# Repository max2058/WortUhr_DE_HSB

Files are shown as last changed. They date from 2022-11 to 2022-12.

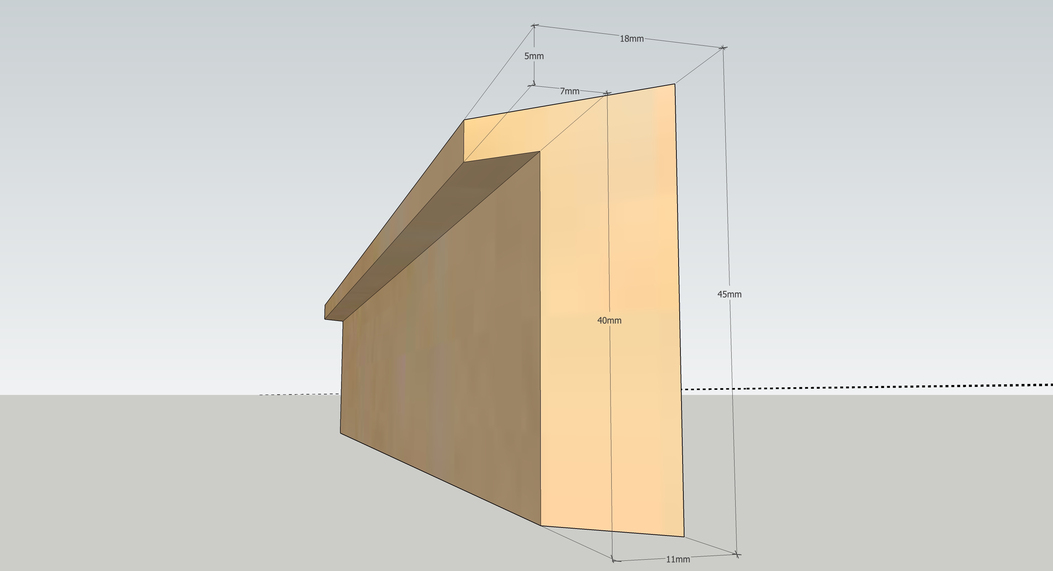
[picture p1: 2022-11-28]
02_Konstruktion_und_Layouts/25x25cm/Rahmen/Rahmen02.jpg

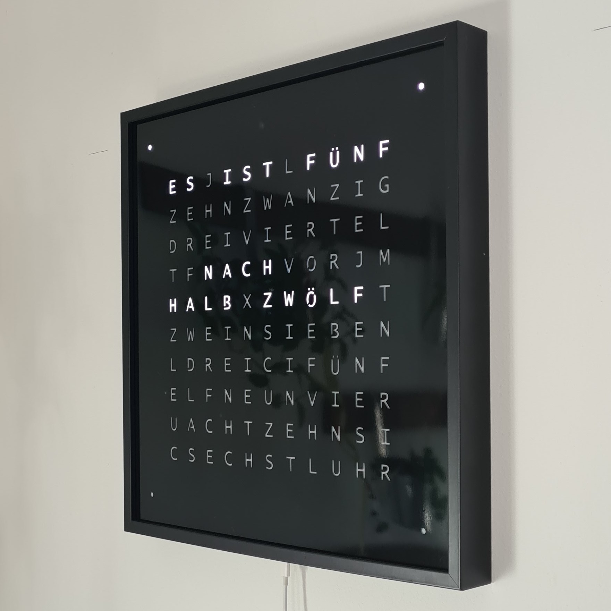
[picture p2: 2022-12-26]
10_Inbetriebnahme/01_Bilder/20220212_113719~2.jpg

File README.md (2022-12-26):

# WortUhr / WordClock

Projekt Wortuhr.... Text

## Hinweis

Hier liegt das "Gesamte" WortUhr Projekt und nicht nur der Quellcode der Software...

## Inhalt

- 02_Konstruktion_und_Layouts.             --> 3D Zeichungen Uhr, Rahmen; 3D-Druck Teile, Schriftart, PDF- Layout 
- 03_Programm_ESP8266/WordUhr_DE_Esp8266.  --> C-Quellcode Programm Arduino ESP8266
- 10_Inbetriebnahme        --> Hinweise Inbetriebnhame (pdf), Diverse Bilder
- 50_SorbischeWordUhrDok.  --> Ist in Planung, Erste Dokumente
- 99_WeitereUnterlagen.    --> Datenblätter ESP8266

... in Bearbeitung
...

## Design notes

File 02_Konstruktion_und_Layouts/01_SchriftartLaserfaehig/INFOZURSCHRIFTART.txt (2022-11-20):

Bei meinen Layouts habe ich die Schriftart '84Lucida-Console' selbst angepasst und "erweitert" um eine Laserbare bzw Plottbare Schriftart zu haben. "Lucida-Console" sieht ganz cool aus, ist im Original aber keine "Standsbare" Schriftart..}

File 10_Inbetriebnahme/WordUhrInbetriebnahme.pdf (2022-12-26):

# WORTUHR / WORDCLOCK

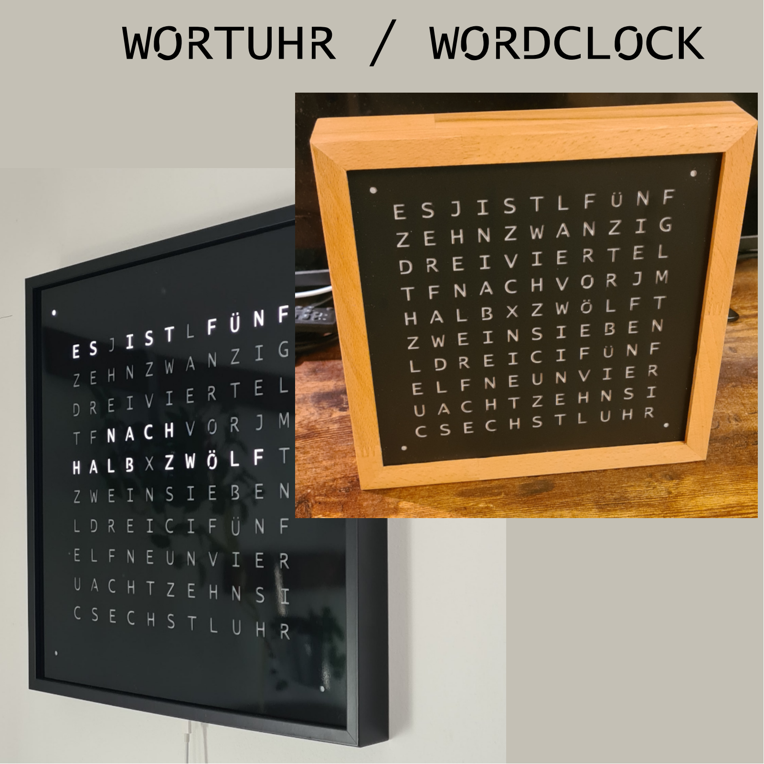
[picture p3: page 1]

# AUFBAU

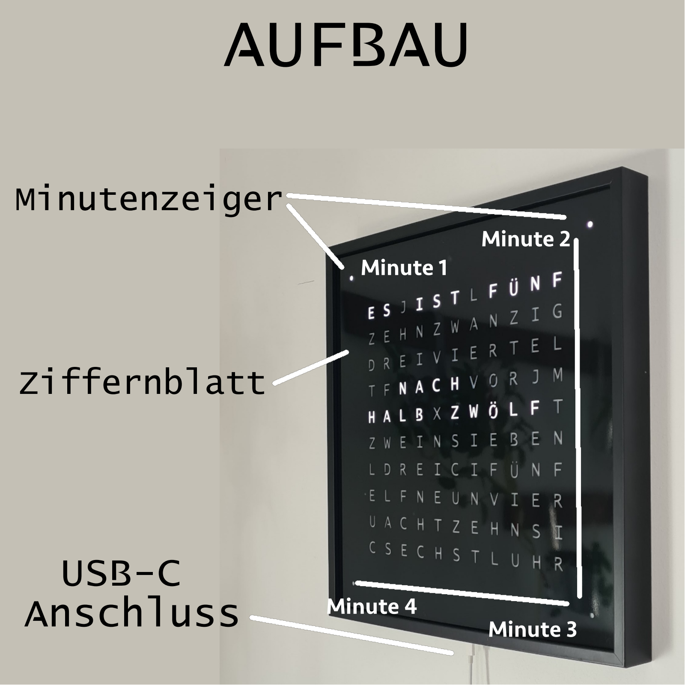
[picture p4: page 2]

# USB-C Anschluss

## Ziffernblatt

## Minutenzeiger

### Minute 1

### Minute 2

### Minute 3

### Minute 4

1. Die WortUhr mit dem beigelegten USB-Kabel + Netzteil an eine Steckdose stecken.
2. Die Uhr startet und führt einen LED Test durch.
3. Nun mit einem Smartphone, Tablet oder PC sich über WLAN mit der WortUhr verbinden.

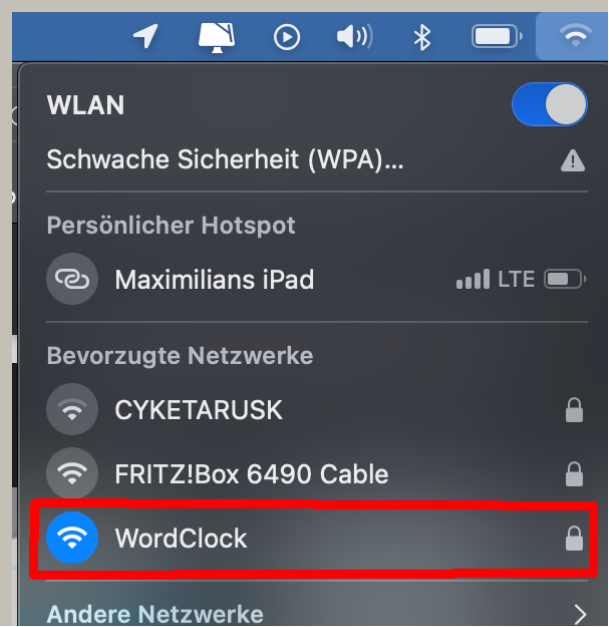
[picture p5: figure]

NAME: "WordClock" oder
"WortUhr"
(je nach Version)

Passwort: "wortuhr123"

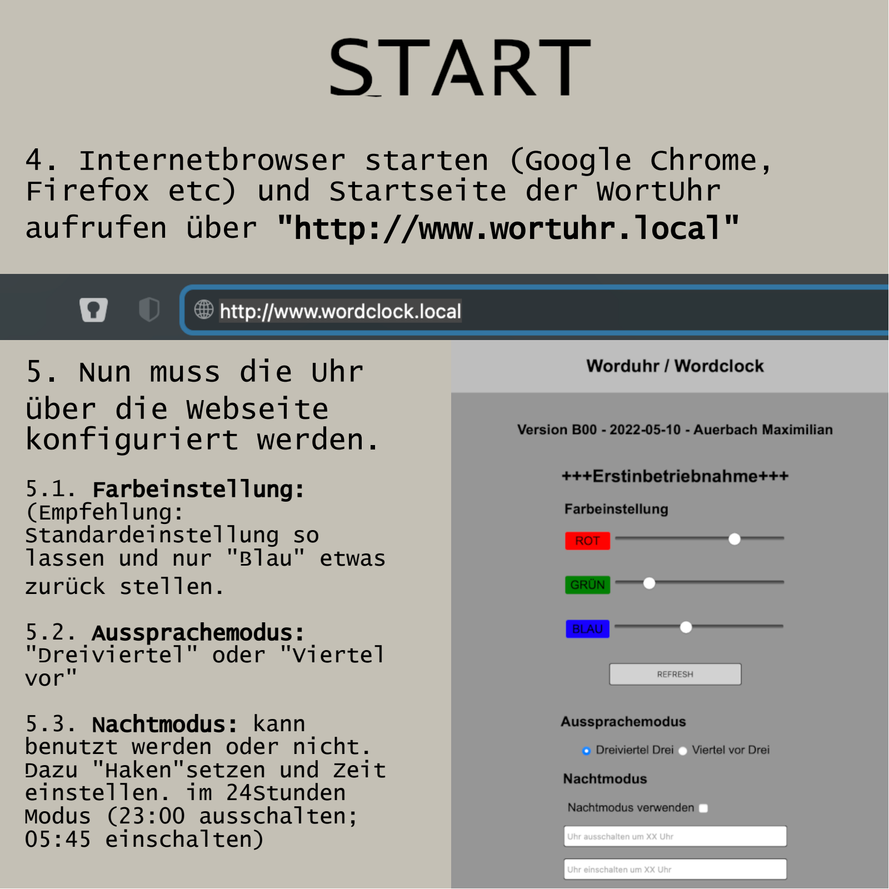
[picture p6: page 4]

4. Internetbrowser starten (Google Chrome, Firefox etc) und Startseite der WortUhr aufrufen über "http://www.wortuhr.local"
5. Nun muss die Uhr
über die Webseite
konfiguriert werden.
5.1. Farbeinstellung:
(Empfehlung:
Standardeinstellung so
lassen und nur "Blau" etwas zurück stellen.
5.2. Aussprachemodus:
"Dreiviertel" oder "Viertel vor"
5.3. Nachtmodus: kann
benutzt werden oder nicht. Dazu "Haken"setzen und Zeit einstellen. im 24Stunden
Modus (23:00 ausschalten;
05:45 einschalten)

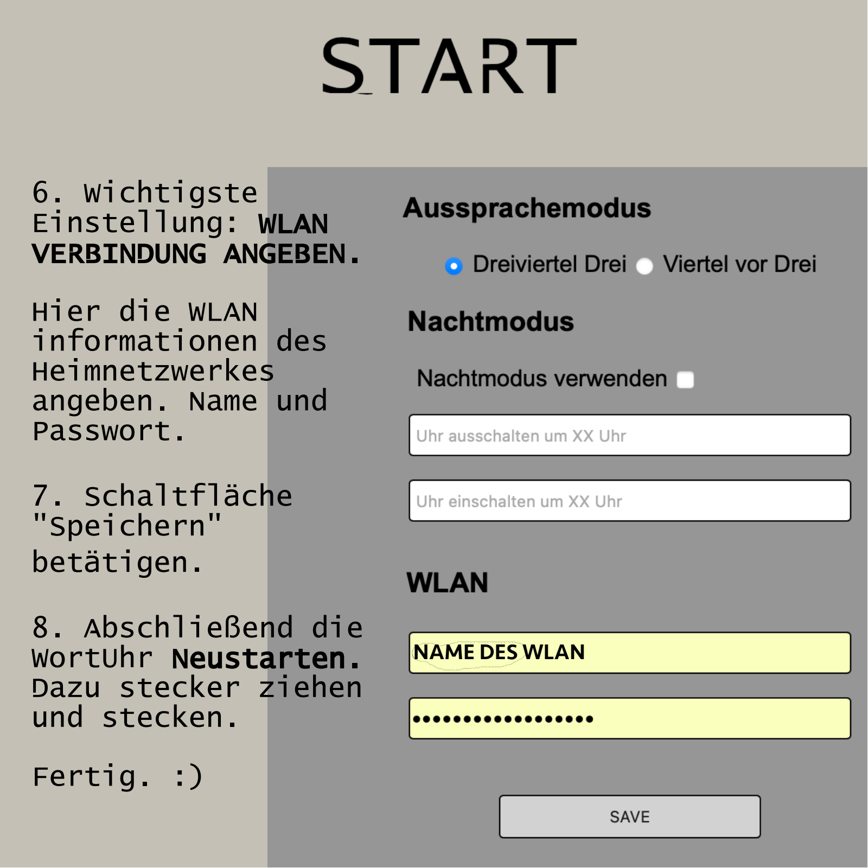
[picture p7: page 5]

6. Wichtigste
Einstellung: WLAN
VERBINDUNG ANGEBEN.

Hier die WLAN
informationen des
Heimnetzwerkes
angeben. Name und
Passwort.
7. Schaltfläche
"Speichern"
betätigen.
8. Abschließend die
WortUhr Neustarten.
Dazu stecker ziehen
und stecken.

Fertig. :)

NAME DES WLAN

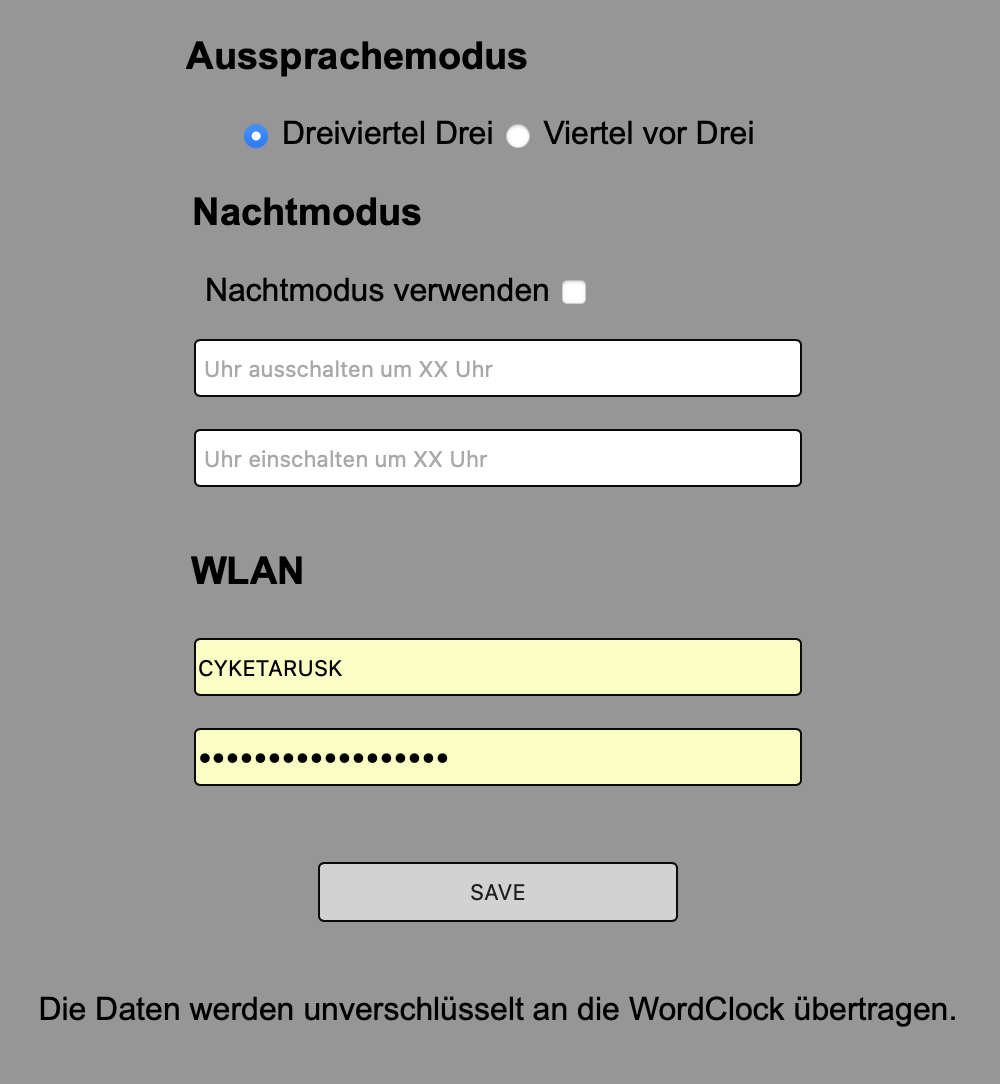
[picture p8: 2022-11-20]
10_Inbetriebnahme/01_Bilder/Bildschirmfoto 2022-04-28 um 17.10.47.png

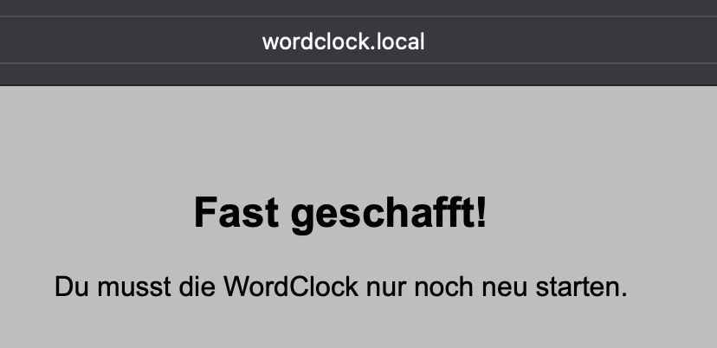
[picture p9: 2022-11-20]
10_Inbetriebnahme/01_Bilder/Bildschirmfoto 2022-04-28 um 17.11.06.png

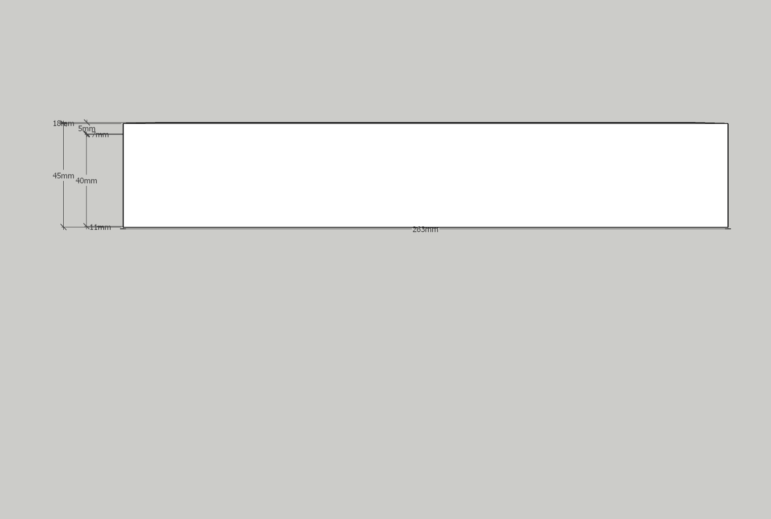
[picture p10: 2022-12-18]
02_Konstruktion_und_Layouts/25x25cm/Rahmen/Rahmen04_Hinten.png

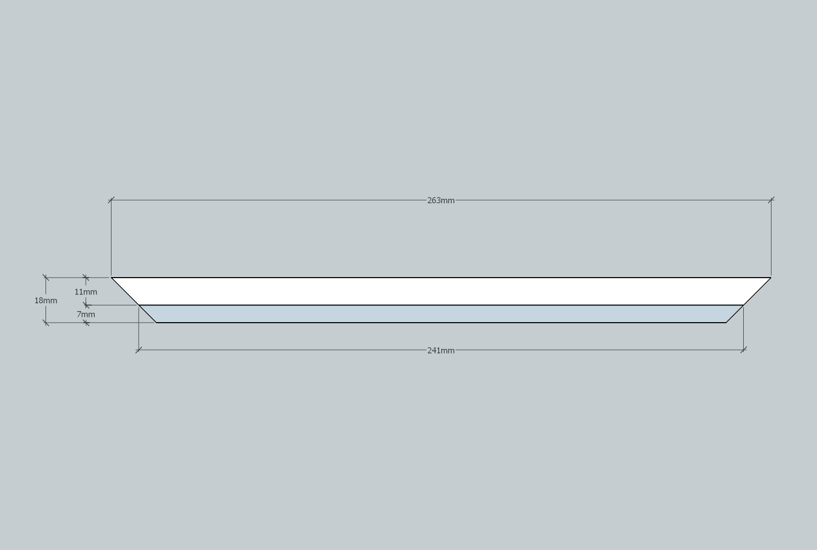
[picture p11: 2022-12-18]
02_Konstruktion_und_Layouts/25x25cm/Rahmen/Rahmen02_Unten.png

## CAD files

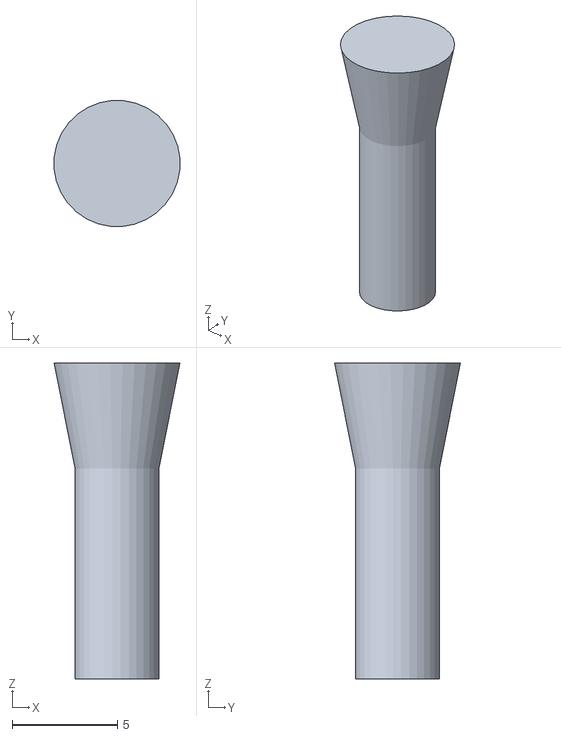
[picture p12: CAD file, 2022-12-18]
02_Konstruktion_und_Layouts/25x25cm/Schliessstem.stl
5.98 x 5.98 x 15.0

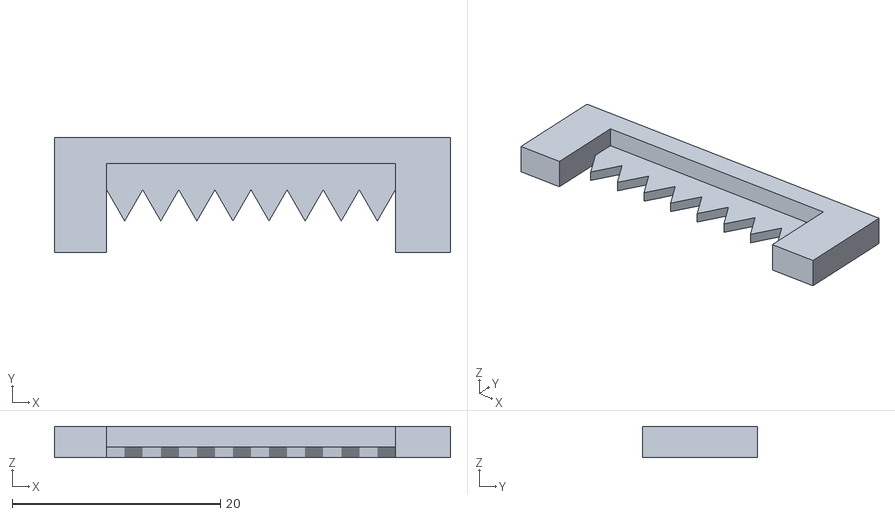
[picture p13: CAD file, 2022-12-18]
02_Konstruktion_und_Layouts/WandhalterNagelBilderrahmen_klein.stl
38.0 x 11.0 x 3.00

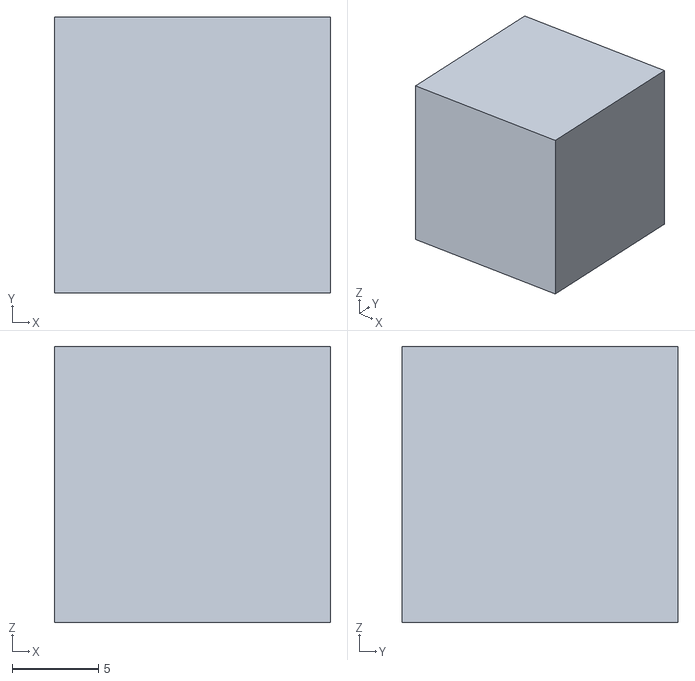
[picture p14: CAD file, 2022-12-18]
02_Konstruktion_und_Layouts/25x25cm/Abstandshalter.stl
16.0 x 16.0 x 16.0

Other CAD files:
02_Konstruktion_und_Layouts/25x25cm/LayoutLED60ProMeter.skp
02_Konstruktion_und_Layouts/25x25cm/LayoutLED60ProMeter~.skp
02_Konstruktion_und_Layouts/WandhalterNagelBilderrahmen_klein.skp
02_Konstruktion_und_Layouts/WandhalterNagelBilderrahmen_klein~.skp

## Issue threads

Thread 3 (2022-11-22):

Manchmal wird der ESP8266 zerstört.

max2058, 2022-11-22:
dann qualmt ein Bauteil ab... Die Vermutung ist, dass die LEDs zu hell eingestellt werden und die Stromaufnahme zu groß ist.. Das passiert bevorzugt gleich immer zu beginn beim LED test während der IBN... weil da sind kurz alle Lampen an....
Problem:
- ist nur eine Vermutung...
- das SMD Bauteil welches durchraucht --> keine Ahnung was das für eine Aufgabe hat.

max2058, 2022-11-25:
Habe die LED Helligkeit während des LED testes nun auf ein Minimum verringert..

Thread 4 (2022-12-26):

Nachtmodus kann unsauber konfiguriert werden.

max2058, 2022-12-26:
wenn man bei der Inbetriebnahme nur den Haken bei "Nachtmodus" setzt, und keine Uhrzeiten einträgt, dann geht die Uhr einfach direkt aus nach dem start... und der Nachrmodus ist dann quasi von 0 bis 24 Uhr

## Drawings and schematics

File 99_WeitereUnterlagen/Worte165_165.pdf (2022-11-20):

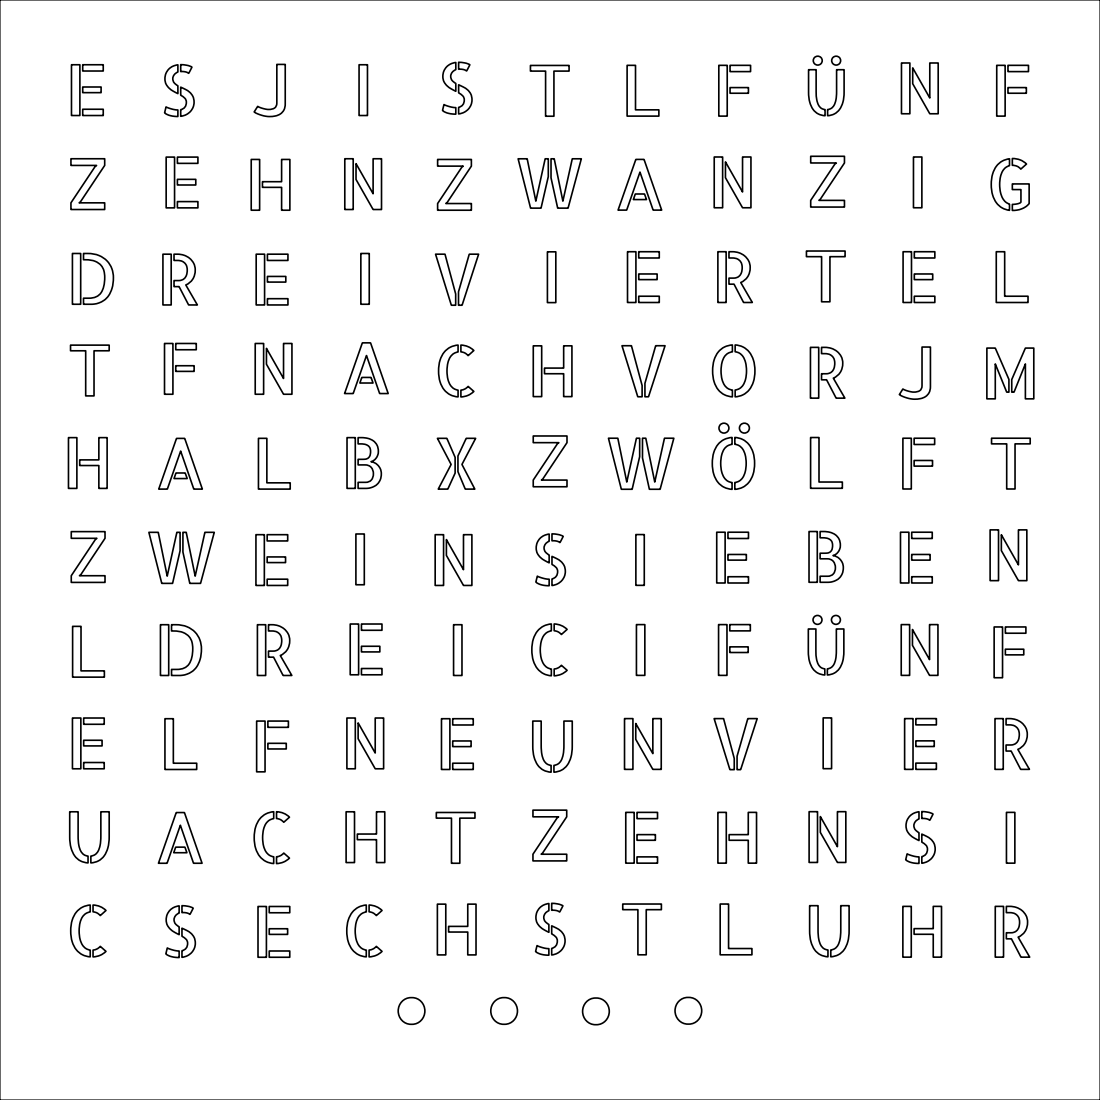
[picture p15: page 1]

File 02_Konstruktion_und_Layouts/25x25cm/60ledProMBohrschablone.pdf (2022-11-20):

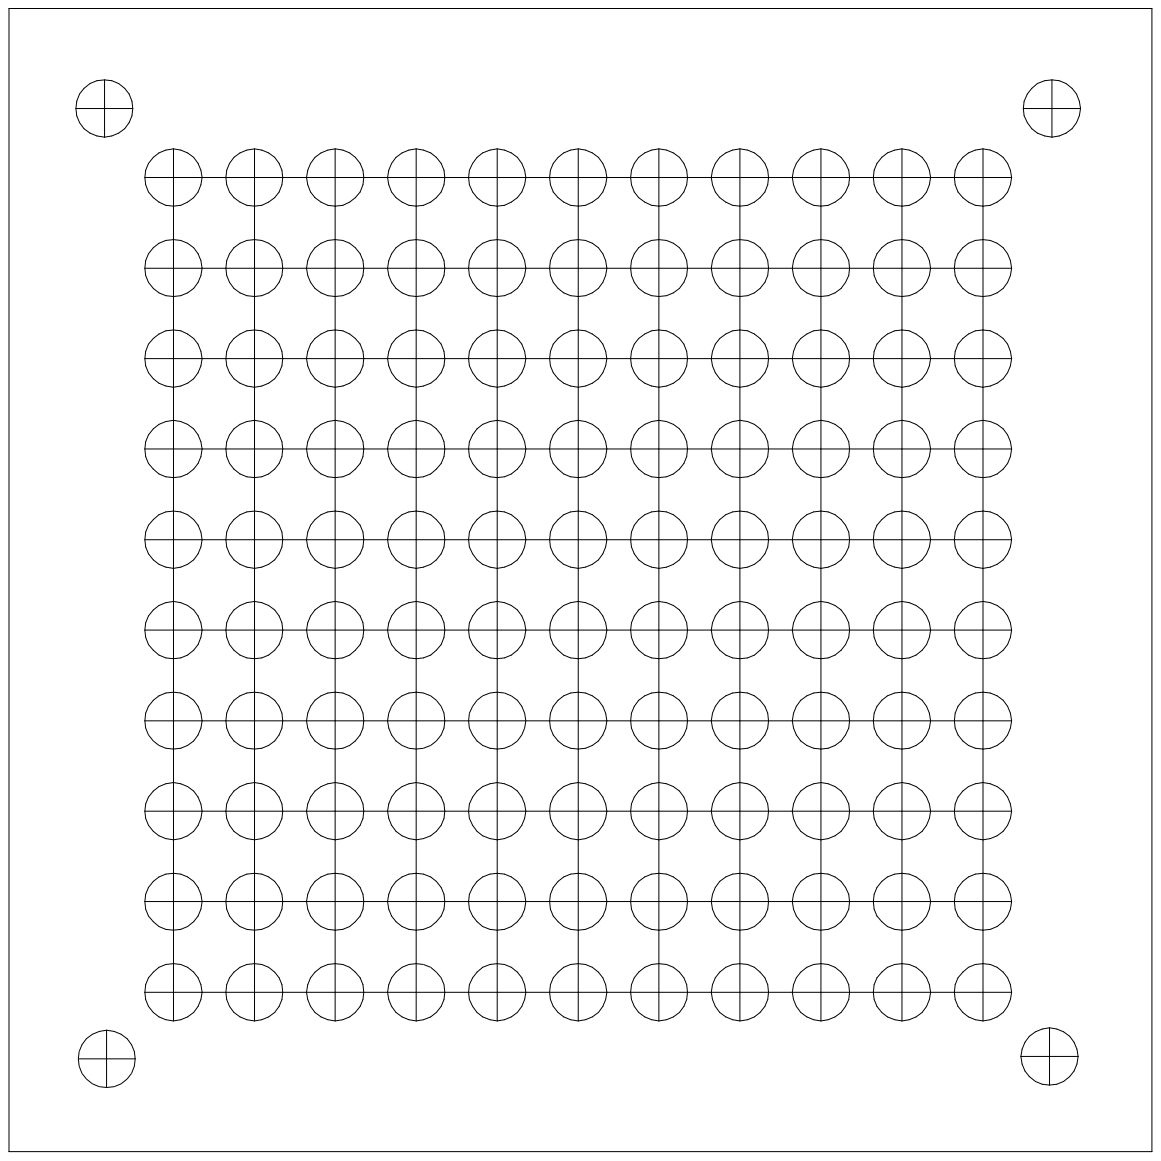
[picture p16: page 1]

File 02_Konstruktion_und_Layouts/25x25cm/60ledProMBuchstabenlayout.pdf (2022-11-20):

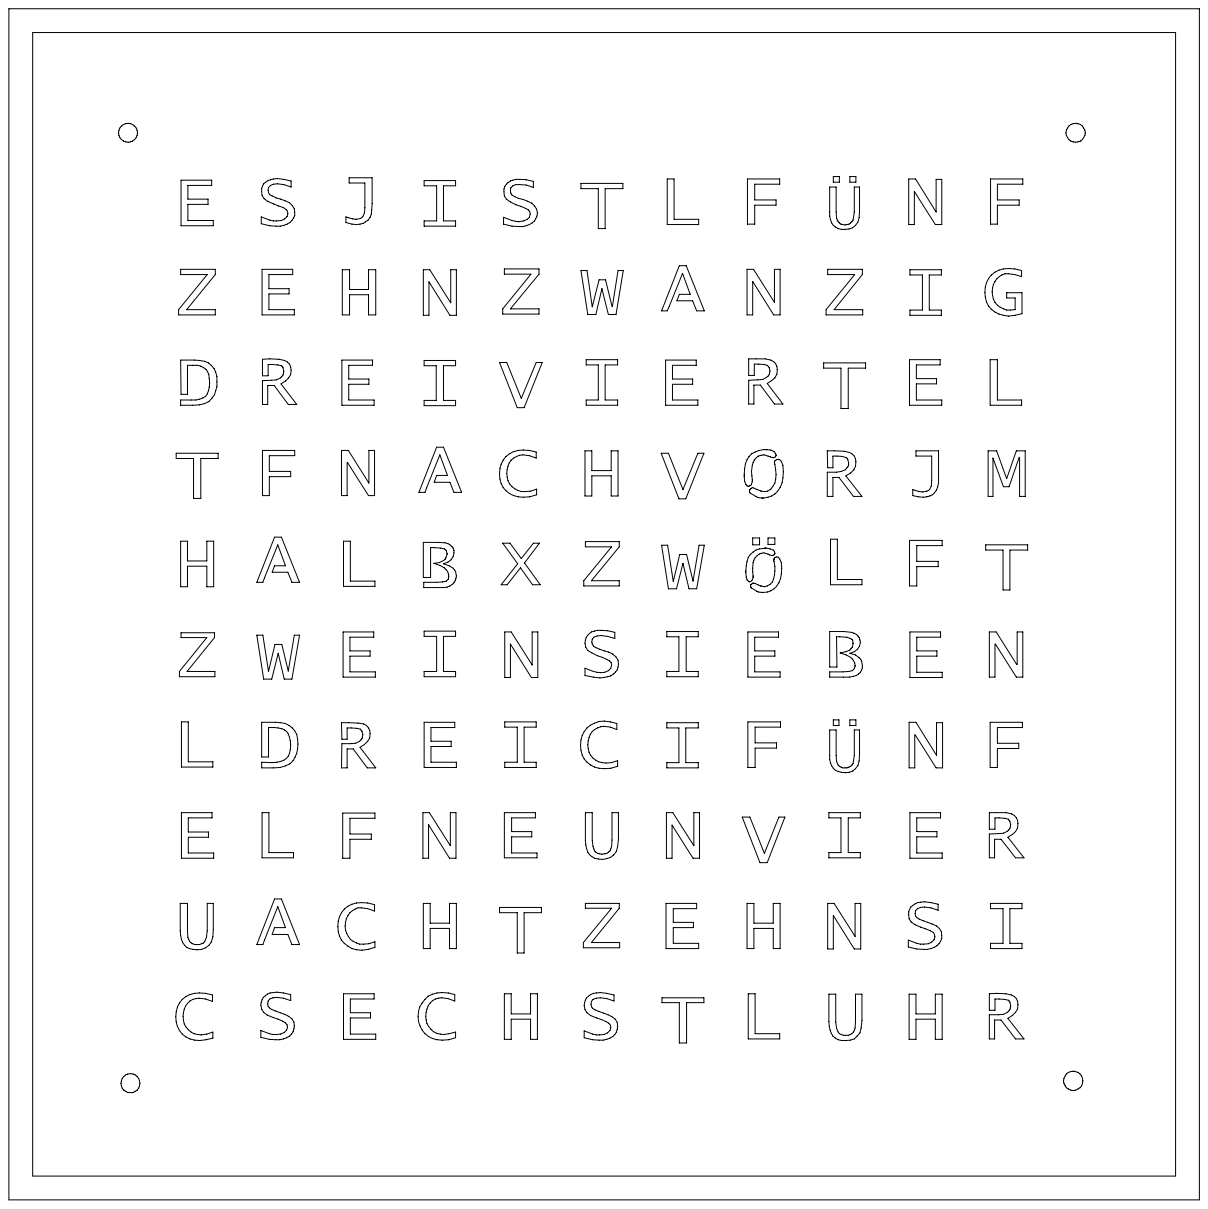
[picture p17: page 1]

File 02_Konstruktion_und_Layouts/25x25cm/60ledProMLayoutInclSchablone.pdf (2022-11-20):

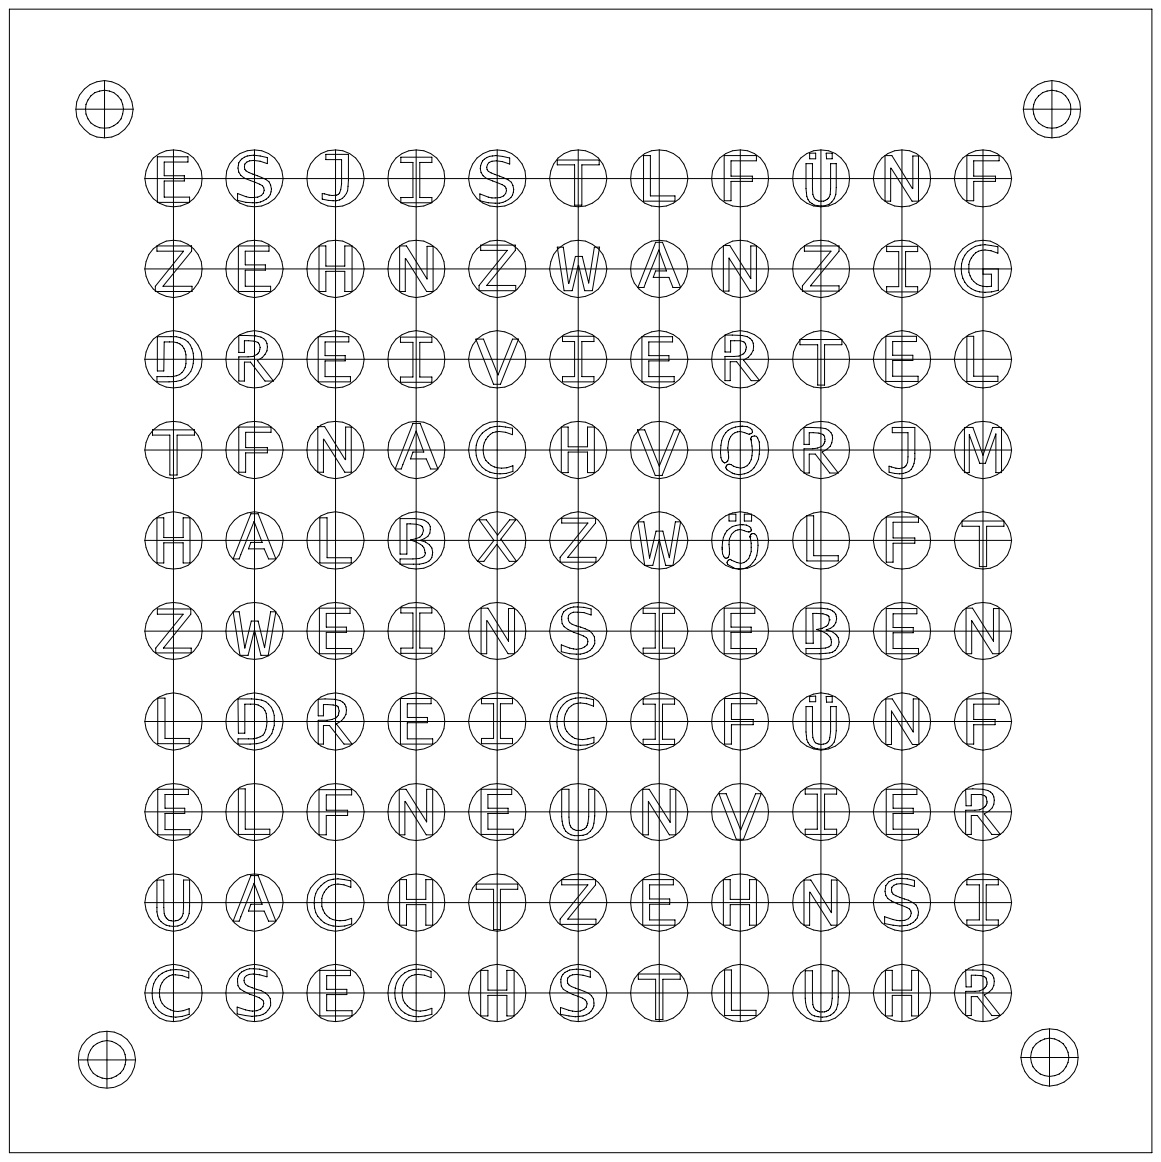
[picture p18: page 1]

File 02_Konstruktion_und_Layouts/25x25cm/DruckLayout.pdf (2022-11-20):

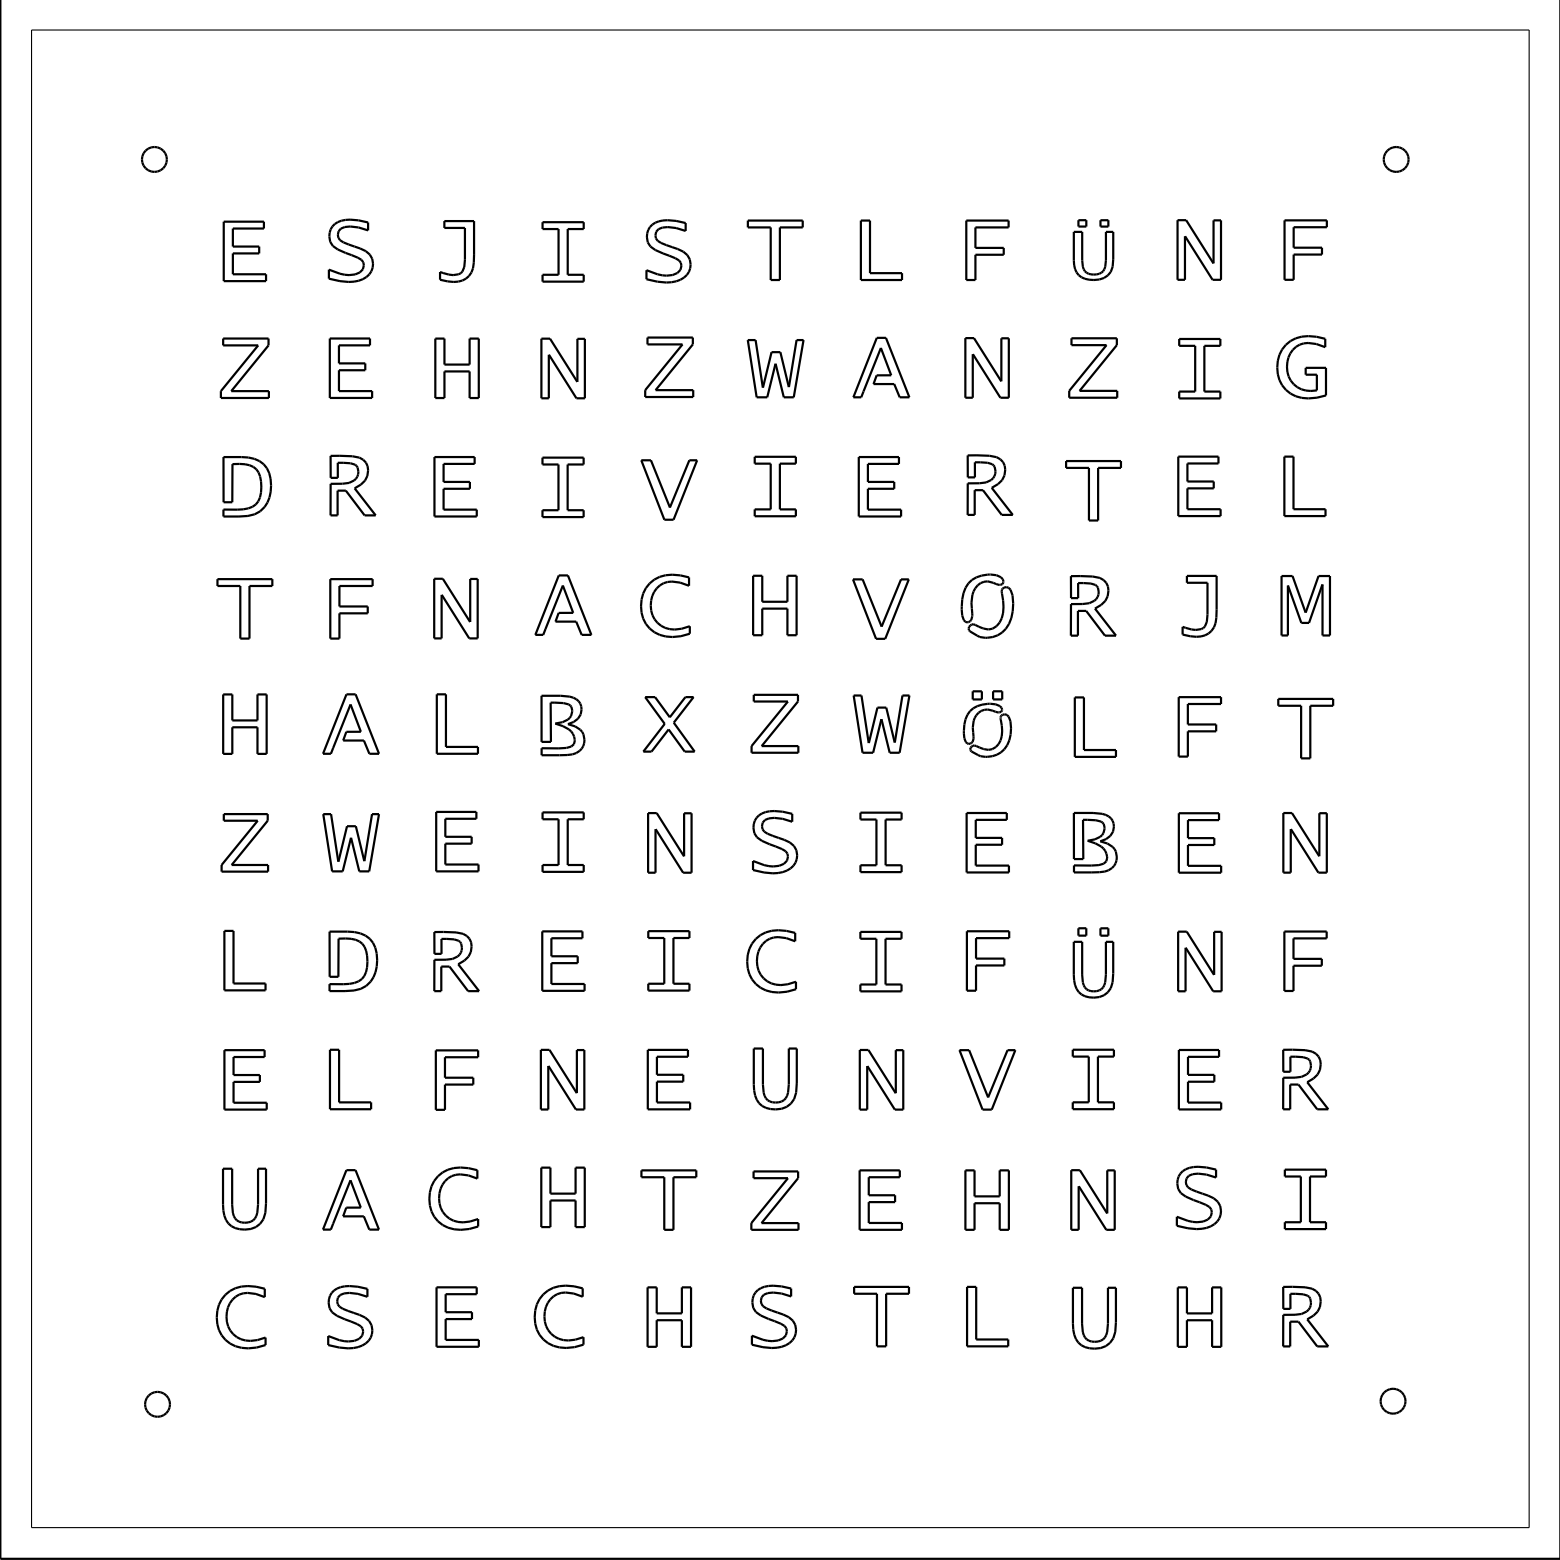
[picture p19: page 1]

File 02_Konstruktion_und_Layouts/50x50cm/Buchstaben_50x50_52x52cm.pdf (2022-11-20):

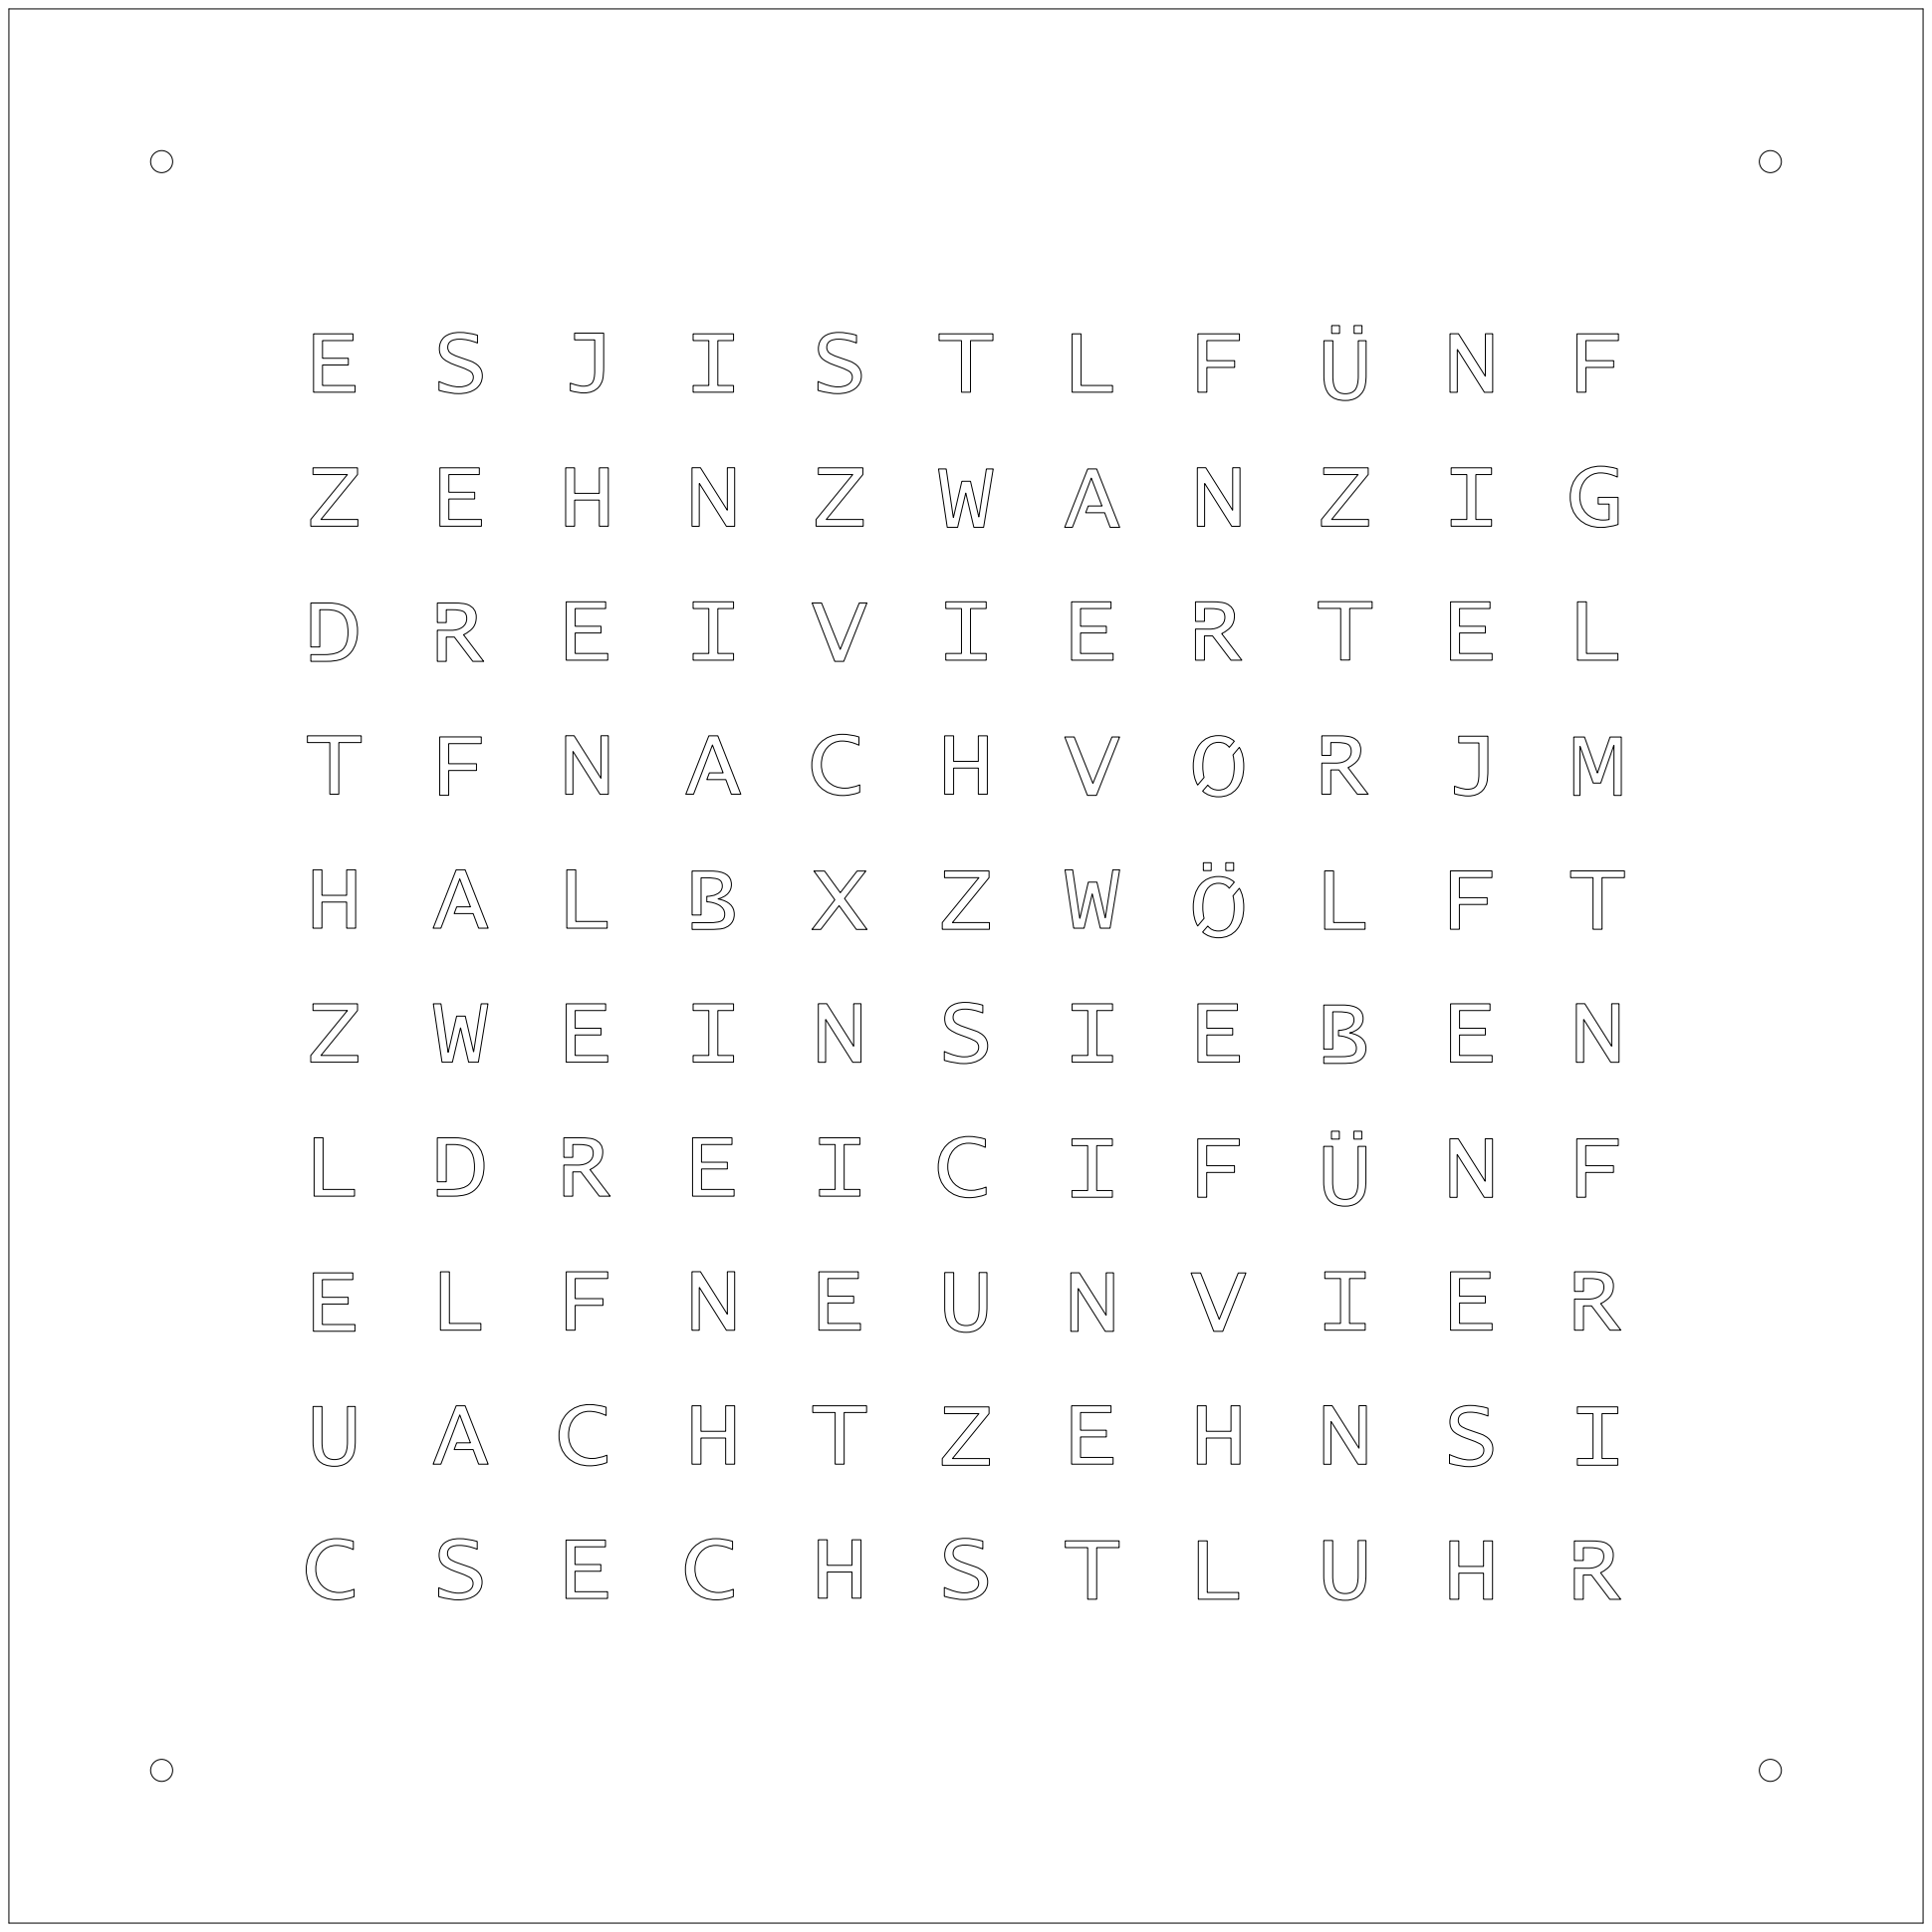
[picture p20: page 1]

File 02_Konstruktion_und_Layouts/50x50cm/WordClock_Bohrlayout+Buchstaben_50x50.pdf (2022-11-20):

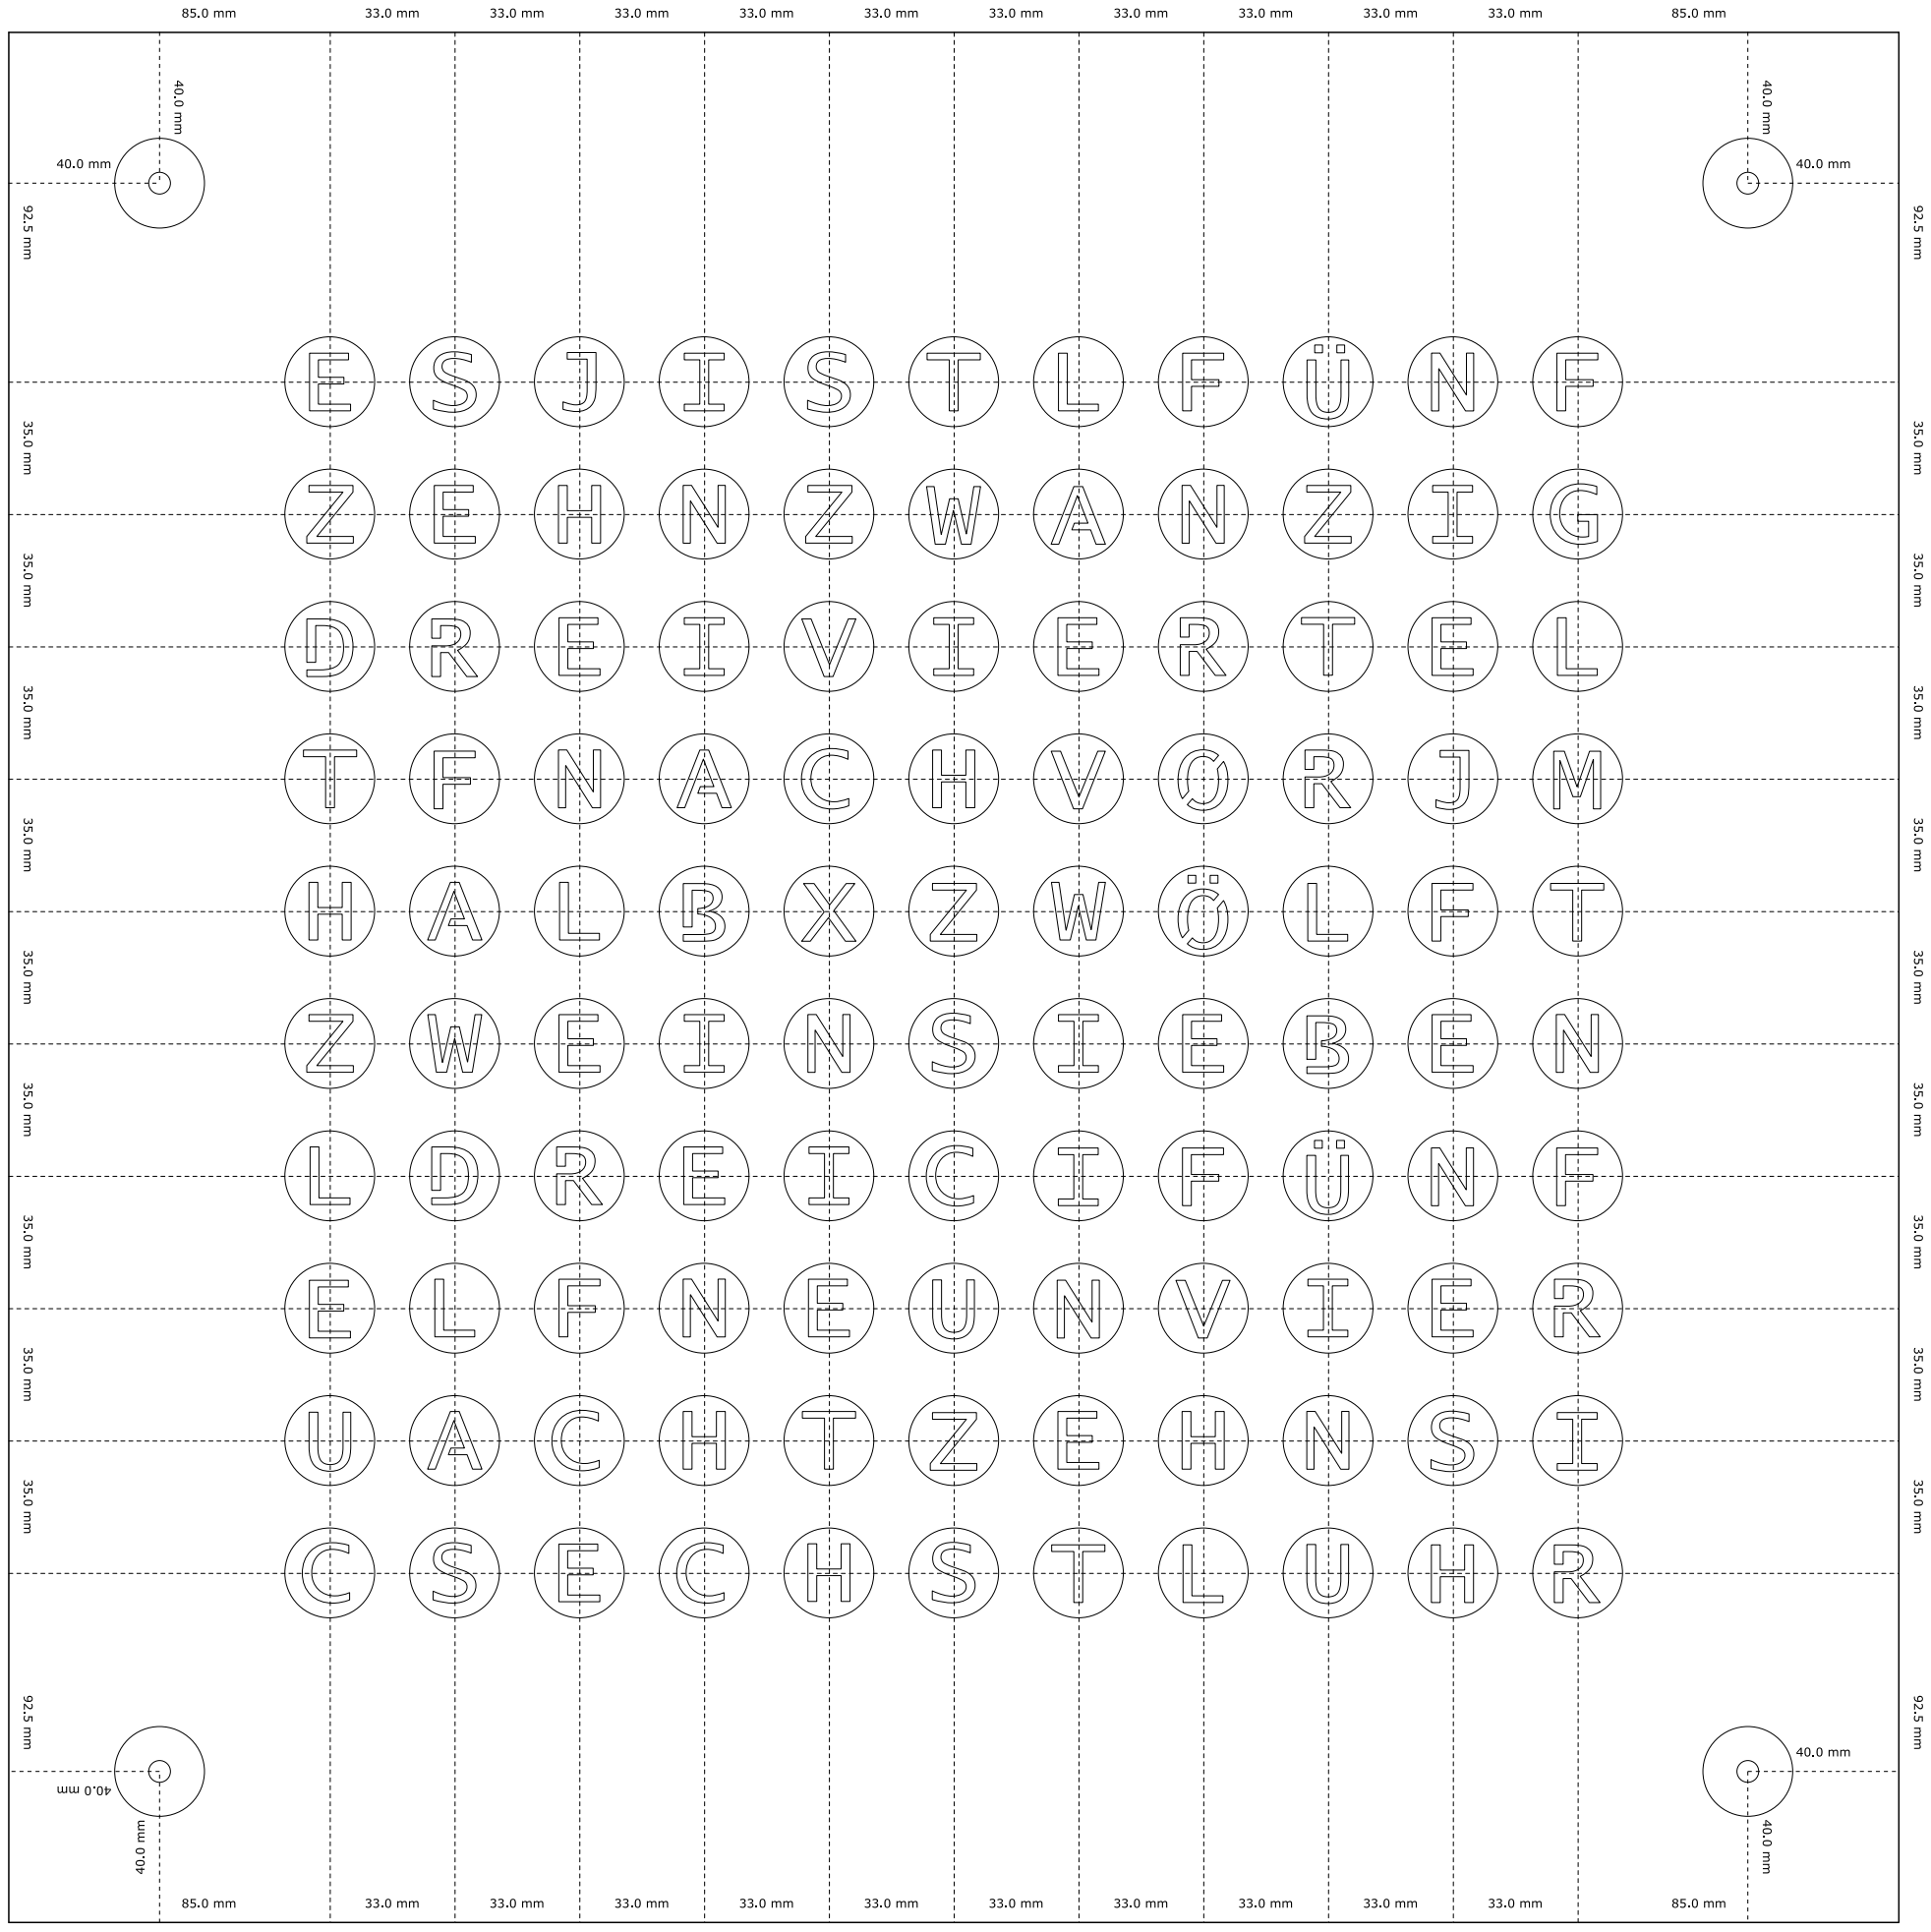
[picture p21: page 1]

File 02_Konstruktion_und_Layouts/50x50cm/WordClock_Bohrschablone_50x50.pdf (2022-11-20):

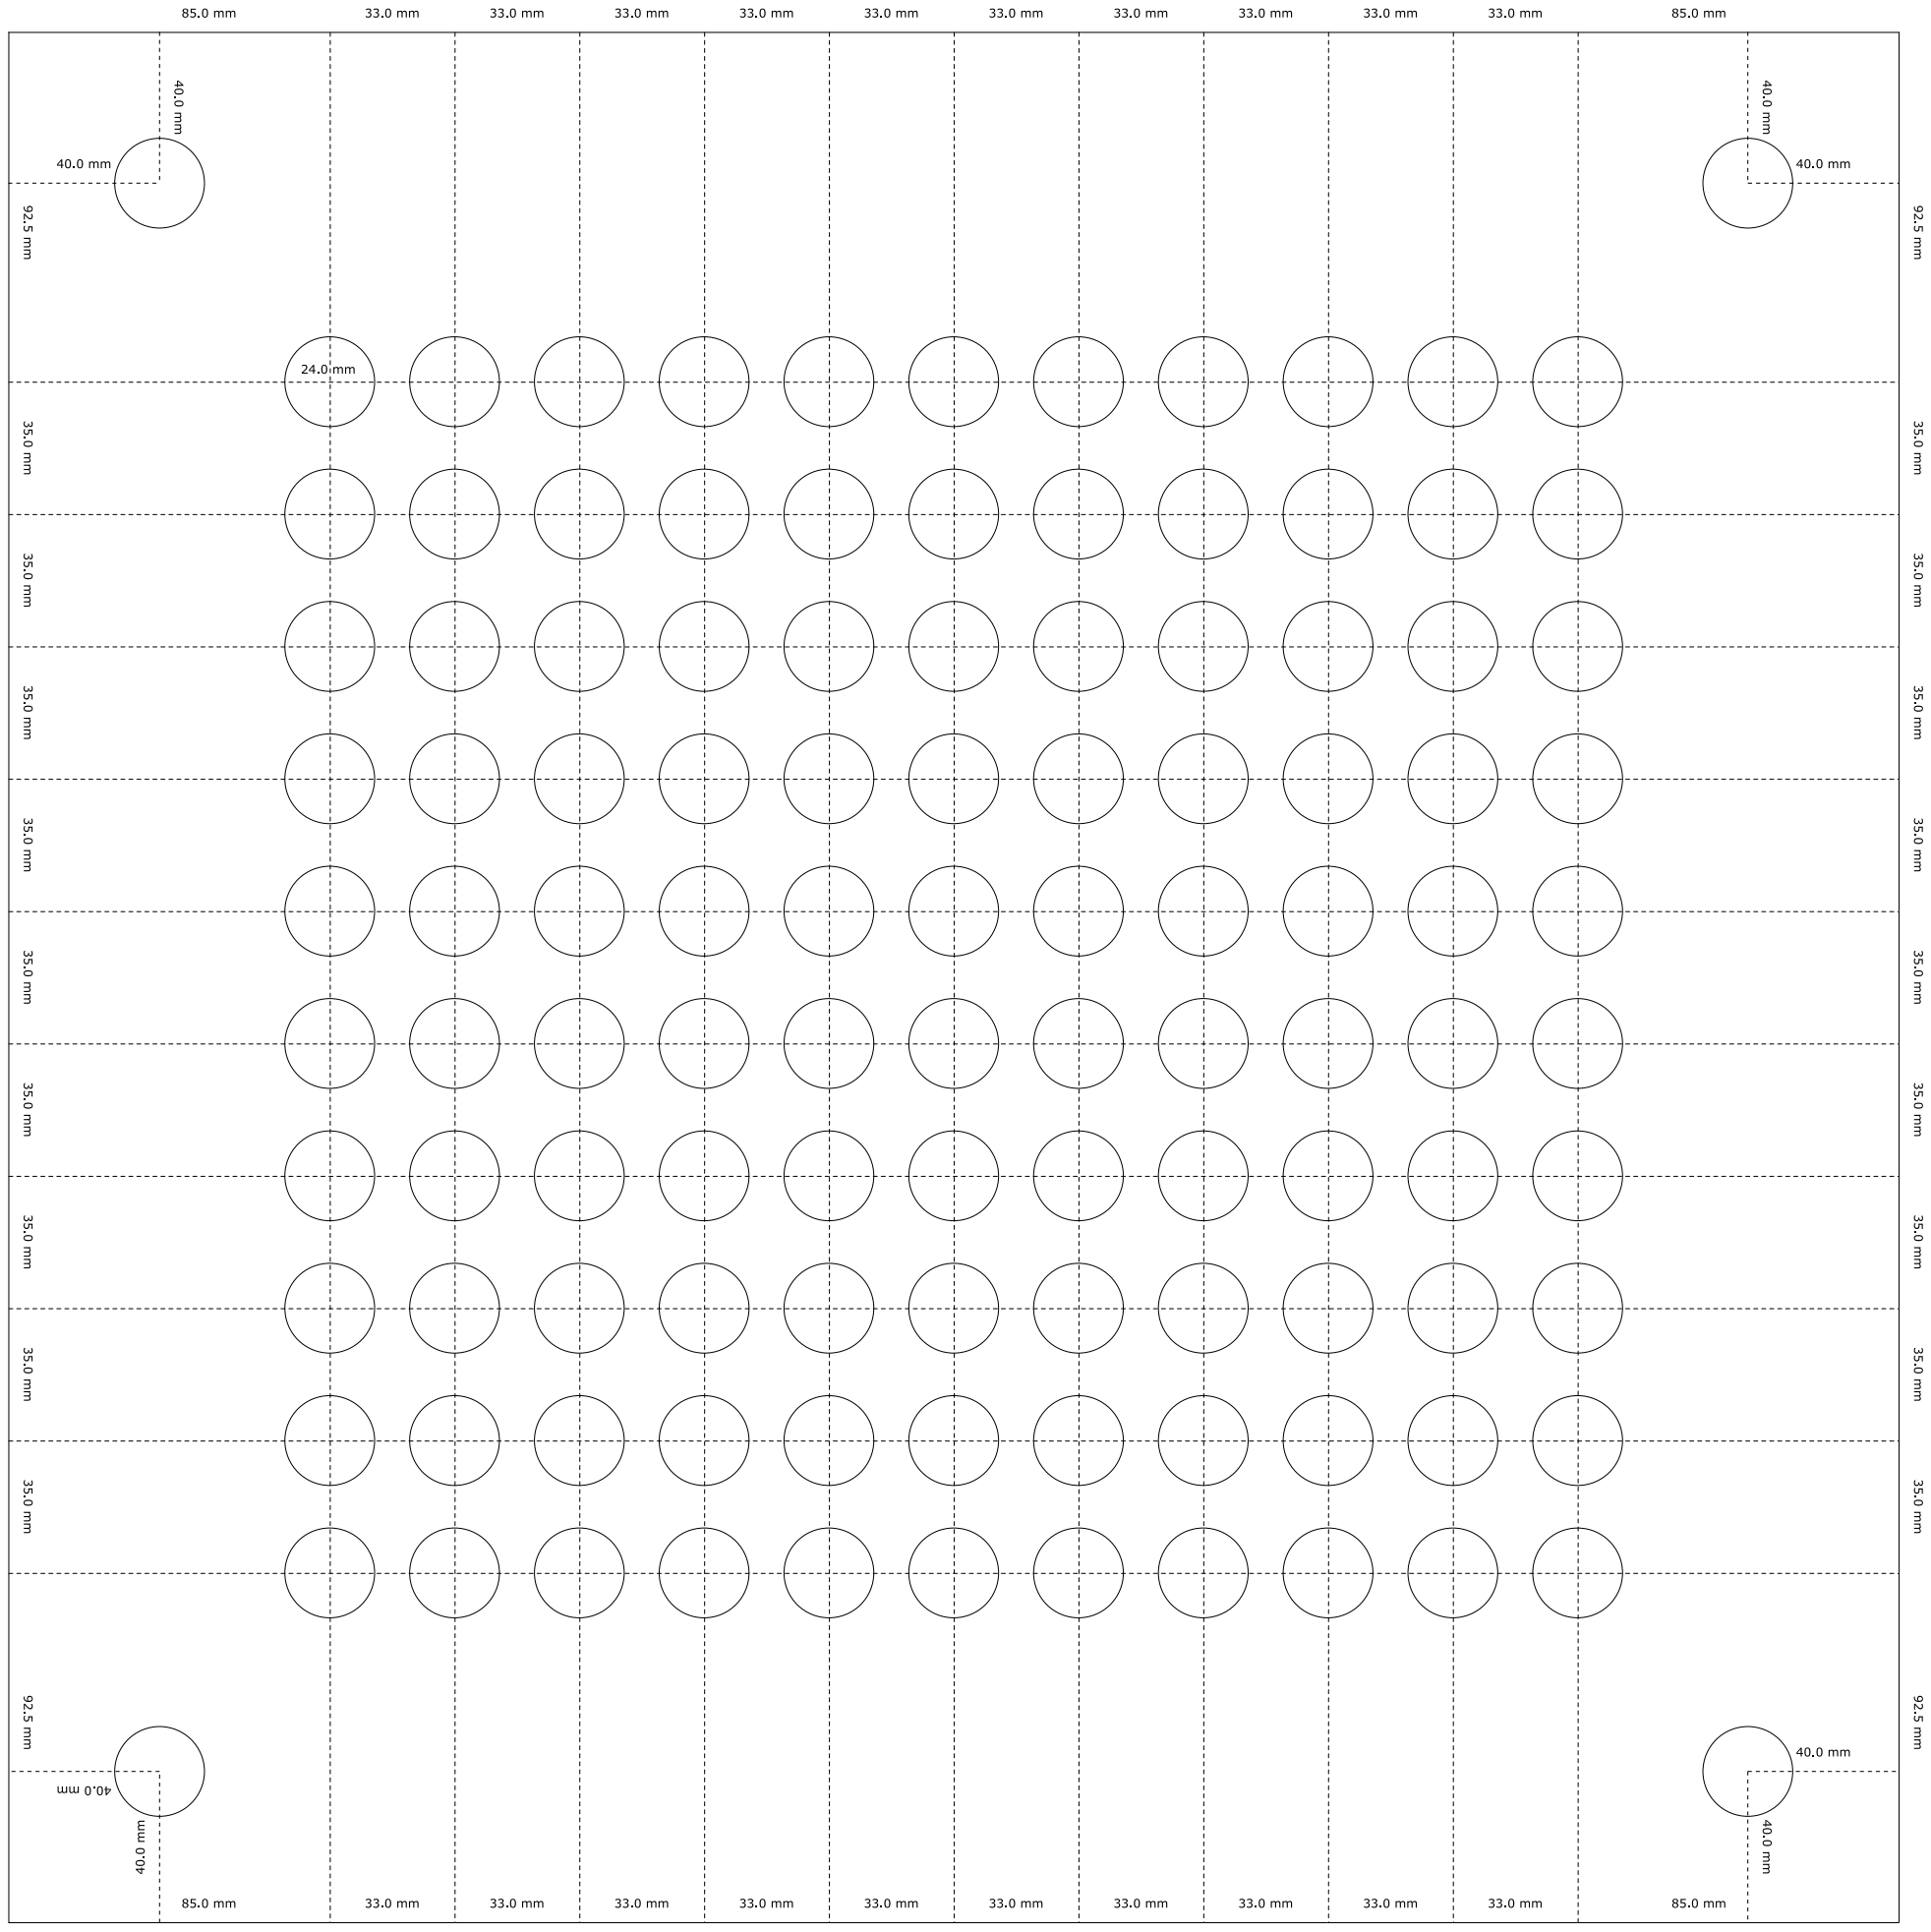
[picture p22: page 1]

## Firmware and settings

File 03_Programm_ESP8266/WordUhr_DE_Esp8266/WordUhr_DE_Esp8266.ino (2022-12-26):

/*
 * Projekt: WortUhr / WordClock 
 * Ersterstellung: 10.01.2022
 *
 * Version: 1.3.0.6
 * Aenderungsdatum: 26.12.2022
 * Autor: Auerbach Maximilian - max.auerbach@gmx.net  
 * 
 * Changelog:
 * --- Bugfixes
 * - Fehler Stundenzahl erhöhen ab HALB
 * - Fehler Dimmwert für BLAU berechnen
 * - Fehler Sonderfall EIN/EINS
 * - Fehler Issue #2 unklare sporadische Zerstörung des ESP8266. (siehe GitHub)
 * --- Neuerungen
 * + Ergänzung Ost-Variante ("viertel vor" vs. "dreiviertel") User kann bei Inbetriebnahme (über DNS Server) auswahl treffen.
 * 
 *
*/

//Externe Bibliotheken
#include <ESP8266WiFi.h>
#include <WiFiUdp.h>
#include <Adafruit_NeoPixel.h>
#include <Wire.h>
#include <EEPROM.h>
#include <ESP8266WebServer.h>
#include <DNSServer.h>
#include "Parameter.h"
#include "HTML.h"



//******************************************************** PARAMETER ********************************************************
//********************************************************** WS2812B ********************************************************

//Pin des ESP8266
const uint16_t Pin = D6;

//Bitte auswählen, welcher WordClock-Typ verwendet wird
// TYPE  0  => für eine WordClock ohne Minutenanzeige
// TYPE  1  => für eine WordClock mit Minutenanzeige
#define TYPE 1

//WordClock ohne Minutenanzeige
#if TYPE == 0
  bool WordClockType = LOW;
  //Anzahl der LED's
  const uint16_t Numbers = 110;
#endif

//WordClock mit Minutenanzeige
#if TYPE == 1
  bool WordClockType = HIGH;
  //Anzahl der LED's
  const uint16_t Numbers = 114;
#endif

//***************************************************************************************************************************
//*********************************************** ACCESS POINT & DNS SERVER *************************************************

//Zugangsdaten Access Point
//SSID
const char SSID_AccessPoint[] = "WortUhr";
//Passwort
const char Password_AccessPoint[] = "wortuhr123";
//URL DNS Server
//www.wortuhr.local
const char WebserverURL[] = "www.wortuhr.local";

//***************************************************************************************************************************
//******************************************* FARBWERTE UND HELLIGKEIT DER LED's ********************************************

//Beispiel: RGB-Farbschema Rot = 50; Grün = 50; Blau = 50 => ergibt einen weißen Farbton.
//Tipp: Der blaue Anteil muss bei den WS2812B-LED's etwas reduziert werden, da dieser dominanter ausfällt.
//Helligkeit der LED's kann mit Werten zwischen 0 - 255 eingestellt werden.
//Beispiel 1: Rot = 255;  Grün = 255; Blau = 255 => weißer Farbton mit maximaler Helligkeit aller LED's
//Beispiel 2: Rot = 0;    Grün = 0;   Blau = 255 => blauer Farbton mir maximaler Helligkeit der blauen LED
//Beispiel 3: Rot = 127;  Grün = 127; Blau = 127 => weißer Farbton mit 50% der Helligkeit aller LED's

//Farbwert ROT
const unsigned int RGBValueRed = 60;
//Farbwert GRÜN
const unsigned int RGBValueGreen = 60;
//Farbwert BLAU
const unsigned int RGBValueBlue = 50;


//***************************************************************************************************************************
//******************************************************** Modi *************************************************************
//******************************************************** Ost Oder West ****************************************************

//Variable für Ost Oder West - im Verlauf:
// TYPE  0  => für (viertel Vor Drei, viertel nach zwei)
// TYPE  1  => für (dreivirtel drei, viertel drei)
unsigned int EastWest;

//******************************************************** NACHTMODUS *******************************************************
//Display kann in einem definiertem Zeitfenster (24h-Format) ausgeschalten werden.
//Enable Display On/Off => Freigabe der Funktion
//Display Off => Uhrzeit wann das Display wieder ausgeschaltet werden soll
//Display On => Uhrzeit wann das Display wieder eingeschaltet werden soll

//Freigabe der Funktion
unsigned int EnableNightMode = 0;
//Uhrzeit Display ausschalten
unsigned int TimeDisplayOff = 0;
//Uhrzeit Display einschalten
unsigned int TimeDisplayOn = 0;


//***************************************************************************************************************************
//***************************************************** LOKALE UHRZEIT ******************************************************

//Wird die Uhr ohne eine WLAN-Verbindung gestartet, kann mit den folgenden Parametern eine Uhrzeit eingestellt werden.
//Die Uhrzeit wird als UTC-Zeit eingestellt. Sommerzeit (UTC+2) oder Winterzeit (UTC+1) können eingestellt werden.

//Stundenzahl in UTC (24h-Format)
const unsigned int localutcaktstunde = 11;
//Minutenzahl in UTC
const unsigned int localutcaktminute = 0;
//Sekundenzahl in UTC
const unsigned int localutcaktsekunde = 0;
//Einstellung Sommer-/Winterzeit
const unsigned int localutcx = 1;

//***************************************************************************************************************************
//******************************************************** DIAGNOSE *********************************************************

//Serielle Schnittstelle für die Diagnose öffnen
const bool debug = LOW;

//***************************************************************************************************************************
//******************************************************* KONSTANTEN ********************************************************

//Portnummern
const unsigned int localPort = 2390;
const unsigned int DNSPort = 53;
const unsigned int HTTPPort = 80;

//Adresse des NTP-Serverpools
const char* NtpServerName = "de.pool.ntp.org";

//HTTP Status Codes
const int HTTPRequest = 200;
const int HTTPPost = 303;
const int HTTPNotFound = 404;

//Größe des NTP-Datenpaket
const unsigned int NtpPaketSize = 48;
byte NtpPaketBuffer[NtpPaketSize];

//Größe des UserInterface-Datenpaket
const unsigned int UserInterfacePaketSize = 12;
byte UserInterfacePaketBuffer[UserInterfacePaketSize];

//ID-Nummern
const int UdpIdHandshakeRequest = 100;
const int UdpIdHandshakeAnswer = 101;
const int UdpIdRgb = 102;
const int UdpIdTime = 103;
const int UdpIdDate = 104;
const int UdpIdDisplay = 105;

//Zeitintervalle in Millisekunden
const unsigned long secondperday = 86400;
const unsigned long secondperhour = 3600;
const unsigned long secondperminute = 60;
const unsigned long minuteperhour = 60;
const unsigned long millisecondpersecond = 1000;
const unsigned long IntervallUdp = 20;
const unsigned long IntervallDebug = 10000;
const unsigned long IntervallFade = 3;


//Anzahl der Tage im Monat
unsigned int tageImMonat[13] = { 0, 31, 28, 31, 30, 31, 30, 31, 31, 30, 31, 30, 31 };


//Adresse der ersten und letzten LED
const int ersteLED = 0;
const int letzteLED = Numbers - 1;


//Faktor zur Berechnung der Stromaufnahme
const float currentPerRgbValue = 0.0795;


//Größe der Adressbereiche
const int NumberOfHours = 12;
const int NumberOfMinute = 5;
const int NumberOfAddMinutes = 4;
const int NumberOfSpecialChar = 2;


//Adressen der Stunden
const int HourAddr[NumberOfHours][2] = { { 49, 53 },    //Zwölf
                                         { 60, 63 },    //Eins
                                         { 62, 65 },    //Zwei
                                         { 67, 70 },    //Drei
                                         { 77, 80 },    //Vier
                                         { 73, 76 },    //Fünf
                                         { 104, 108 },  //Sechs
                                         { 55, 60 },    //Sieben
                                         { 89, 92 },    //Acht
                                         { 81, 84 },    //Neun
                                         { 93, 96 },    //Zehn
                                         { 85, 87 } };  //Elf

//Adressen der Minuten
const int MinuteAddr[NumberOfMinute][2] = { { 7, 10 },     //Fünf 0
                                            { 18, 21 },    //Zehn 1
                                            { 26, 32 },    //Viertel 2
                                            { 11, 17 },    //Zwanzig 3
                                            { 22, 32 } };  //Dreiviertel 4

//Adressen Vor/Nach
const int ToPastAddr[NumberOfSpecialChar][2] = { { 38, 41 },    //Nach
                                                 { 35, 37 } };  //Vor

//Adressen Halb/Uhr
const int HalfFullHourAddr[NumberOfSpecialChar][2] = { { 44, 47 },     //Halb
                                                       { 99, 101 } };  //Uhr

//Adressen Es/Ist
const int EsIstAddr[NumberOfSpecialChar][2] = { { 0, 1 },    //Es 0
                                                { 3, 5 } };  //Ist 1

//Adressen der Minutenanzeige
const int AddMinutesAddr[NumberOfAddMinutes][2] = { { 110, 110 },    //Minute +1
                                                    { 111, 111 },    //Minute +2
                                                    { 112, 112 },    //Minute +3
                                                    { 113, 113 } };  //Minute +4

//Zeittabelle mit Takt +2/-2 Minuten
#if TYPE == 0
int TimeTable[60][4] = { { 0, 0, 0, 2 }, { 1, 0, 0, 2 }, { 2, 0, 0, 2 }, { 3, 1, 1, 0 }, { 4, 1, 1, 0 }, { 5, 1, 1, 0 }, { 6, 1, 1, 0 }, { 7, 1, 1, 0 }, { 8, 2, 1, 0 }, { 9, 2, 1, 0 }, { 10, 2, 1, 0 }, { 11, 2, 1, 0 }, { 12, 2, 1, 0 }, { 13, 3, 1, 0 }, { 14, 3, 1, 0 }, { 15, 3, 1, 0 }, { 16, 3, 1, 0 }, { 17, 3, 1, 0 }, { 18, 4, 1, 0 }, { 19, 4, 1, 0 }, { 20, 4, 1, 0 }, { 21, 4, 1, 0 }, { 22, 4, 1, 0 }, { 23, 1, 2, 1 }, { 24, 1, 2, 1 }, { 25, 1, 2, 1 }, { 26, 1, 2, 1 }, { 27, 1, 2, 1 }, { 28, 0, 0, 1 }, { 29, 0, 0, 1 }, { 30, 0, 0, 1 }, { 31, 0, 0, 1 }, { 32, 0, 0, 1 }, { 33, 1, 1, 1 }, { 34, 1, 1, 1 }, { 35, 1, 1, 1 }, { 36, 1, 1, 1 }, { 37, 1, 1, 1 }, { 38, 4, 2, 0 }, { 39, 4, 2, 0 }, { 40, 4, 2, 0 }, { 41, 4, 2, 0 }, { 42, 4, 2, 0 }, { 43, 3, 2, 0 }, { 44, 3, 2, 0 }, { 45, 3, 2, 0 }, { 46, 3, 2, 0 }, { 47, 3, 2, 0 }, { 48, 2, 2, 0 }, { 49, 2, 2, 0 }, { 50, 2, 2, 0 }, { 51, 2, 2, 0 }, { 52, 2, 2, 0 }, { 53, 1, 2, 0 }, { 54, 1, 2, 0 }, { 55, 1, 2, 0 }, { 56, 1, 2, 0 }, { 57, 1, 2, 0 }, { 58, 0, 0, 2 }, { 59, 0, 0, 2 } };
#endif

//Zeittabelle mit Takt volle 5 Minuten
#if TYPE == 1
int TimeTable[60][4] = { { 0, 0, 0, 2 }, { 1, 0, 0, 2 }, { 2, 0, 0, 2 }, { 3, 0, 0, 2 }, { 4, 0, 0, 2 }, { 5, 1, 1, 0 }, { 6, 1, 1, 0 }, { 7, 1, 1, 0 }, { 8, 1, 1, 0 }, { 9, 1, 1, 0 }, { 10, 2, 1, 0 }, { 11, 2, 1, 0 }, { 12, 2, 1, 0 }, { 13, 2, 1, 0 }, { 14, 2, 1, 0 }, { 15, 3, 1, 0 }, { 16, 3, 1, 0 }, { 17, 3, 1, 0 }, { 18, 3, 1, 0 }, { 19, 3, 1, 0 }, { 20, 4, 1, 0 }, { 21, 4, 1, 0 }, { 22, 4, 1, 0 }, { 23, 4, 1, 0 }, { 24, 4, 1, 0 }, { 25, 1, 2, 1 }, { 26, 1, 2, 1 }, { 27, 1, 2, 1 }, { 28, 1, 2, 1 }, { 29, 1, 2, 1 }, { 30, 0, 0, 1 }, { 31, 0, 0, 1 }, { 32, 0, 0, 1 }, { 33, 0, 0, 1 }, { 34, 0, 0, 1 }, { 35, 1, 1, 1 }, { 36, 1, 1, 1 }, { 37, 1, 1, 1 }, { 38, 1, 1, 1 }, { 39, 1, 1, 1 }, { 40, 4, 2, 0 }, { 41, 4, 2, 0 }, { 42, 4, 2, 0 }, { 43, 4, 2, 0 }, { 44, 4, 2, 0 }, { 45, 3, 2, 0 }, { 46, 3, 2, 0 }, { 47, 3, 2, 0 }, { 48, 3, 2, 0 }, { 49, 3, 2, 0 }, { 50, 2, 2, 0 }, { 51, 2, 2, 0 }, { 52, 2, 2, 0 }, { 53, 2, 2, 0 }, { 54, 2, 2, 0 }, { 55, 1, 2, 0 }, { 56, 1, 2, 0 }, { 57, 1, 2, 0 }, { 58, 1, 2, 0 }, { 59, 1, 2, 0 } };
#endif

//***************************************************************************************************************************
//******************************************************** VARIABLEN ********************************************************

int i = 0;
int z = 0;
int x = 0;
int y = 0;

unsigned long newsecsSince1900 = 0;
unsigned long oldsecsSince1900 = 0;

unsigned int oldstunde = 99;
unsigned int oldmezstunde = 0;
unsigned int oldminute = 99;

unsigned int utcaktstunde = 0;
unsigned int utcaktminute = 0;
unsigned int utcaktsekunde = 0;

unsigned int mezaktstunde = 0;
unsigned int mezaktstunde24 = 0;
unsigned int mezaktminute = 0;
unsigned int mezaktsekunde = 0;

unsigned long newtageSeit1900 = 0;
unsigned long oldtageSeit1900 = 0;
unsigned int newschaltTage = 0;

unsigned int wochenTag = 0;

unsigned int datumTag = 0;
unsigned int datumMonat = 0;
unsigned int datumJahr = 0;

unsigned int tagNummer = 0;

unsigned int utcx = 0;

unsigned int oldschaltTage = 0;
bool schaltJahr = LOW;
bool sonderFall366 = LOW;

unsigned long lastmillisDebug = 0;
unsigned long lastmillisSecond = 0;
unsigned long lastmillisdifferenz = 0;
unsigned long lastmillisFade = 0;
unsigned long LastMillisUdp = 0;

unsigned int UdpId = 0;

unsigned int UdpHour = 0;
unsigned int UdpMinute = 0;
unsigned int UdpSecond = 0;

unsigned int UdpDay = 0;
unsigned int UdpMonth = 0;
unsigned int UdpYear = 0;

unsigned int red = 0;
unsigned int green = 0;
unsigned int blue = 0;

float newredminus = 0.0;
float newgreenminus = 0.0;
float newblueminus = 0.0;

float newredplus = 0.0;
float newgreenplus = 0.0;
float newblueplus = 0.0;

float fadevaluered = 1.0;
float fadevaluegreen = 1.0;
float fadevalueblue = 1.0;

unsigned int currentPerLed = 0;

unsigned int pointer = 0;

unsigned int newletter[Numbers];
unsigned int showletter[Numbers];
unsigned int changeletter[Numbers];

bool newdisplay = LOW;
bool setDisplayOff = LOW;
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
void loop() {


  //Start: Webserver

  //Webserver Client
  if (NoWifi == HIGH && newdisplay == LOW) {
    Webserver.handleClient();
    DnsServer.processNextRequest();
  }

  //Ende: Webserver



  //Start: UDP-Datenpakete empfangen

  //UDP-Daten in einem festen Zeitintervall abfragen
  if (millis() - LastMillisUdp > IntervallUdp && newdisplay == LOW) {

    //Systemzeit speichern für den nächsten Vergleich
    LastMillisUdp = millis();

    UdpDataReceive();
  }

  //Ende: UDP-Datenpakete empfangen



  //Start: NTP-Anfrage

  //Zeitwerte bei jedem Stundenwechsel aktualisieren
  if (mezaktstunde != oldmezstunde && newdisplay == LOW && NoWifi == LOW) {

    //Zeit für den nächsten Vergleich speichern
    oldmezstunde = mezaktstunde;

    //Zeitwerte vom NTP-Server anfragen
    SendNtpRequest();
  }

  //Ende: NTP-Anfrage



  //Start: Datum und Uhrzeit ermitteln

  //Kontrolle ob eine Änderung bei dem Zeitstempel stattgefunden hat
  if (newsecsSince1900 > oldsecsSince1900) {

    //Änderung abspeichern für den nächsten Vergleich
    oldsecsSince1900 = newsecsSince1900;

    //Tage seit dem 1. Januar 1900; 00:00:00 Uhr
    newtageSeit1900 = newsecsSince1900 / secondperday;


    //Start: Datum ermitteln

    //Kontrolle ob eine Änderung bei den Tagen seit dem 1. Januar 1900 stattgefunden hat
    if (newtageSeit1900 > oldtageSeit1900) {

      //Änderung abspeichern für den nächsten Vergleich
      oldtageSeit1900 = newtageSeit1900;


      //Aufruf der Funktion zur Berechnung des Wochentages
      wochenTag = wochenTag_calc(newtageSeit1900);


      //Berechnug der Jahreszahl
      datumJahr = ((newtageSeit1900 - newschaltTage) / 365.002f) + 1900;


      //Aufruf der Funktion zur Erkennung ob ein Schaltjahr vorliegt
      schaltJahr = schaltJahrJN(datumJahr);


      //Funktion fürs Schaltjahr
      if (schaltJahr == HIGH) {

        tageImMonat[2] = 29;


        //Anzahl der Schalttage seit dem 1. Januar 1900 !ERST! am Ende des jeweiligen Schaltjahres hochzählen
        //Sonderfall: Zur Berechnung des 366. Tages wird der "alte" Wert der Schalttage benötigt, die Berechnung
        //            der Jahreszahl am 366. Tag muss aber mit dem neuen Wert durchgeführt werden

        //Berechnung der Anzahl der Schalttage seit dem 1. Januar 1900
        if (datumMonat == 12 && datumTag == 30) {

          oldschaltTage = newschaltTage;

          newschaltTage = newschaltTage + 1;

          sonderFall366 = HIGH;
        }
      }

      else {
        tageImMonat[2] = 28;
      }


      //Berechnung der wieviele Tag im Jahr
      //Sonderfall: Die Berechnung des 366. Tages im Schaltjahr muss mit dem "alten" Wert der Schalttage (seit 1900) berechnet werden
      if (sonderFall366 == HIGH) {

        tagNummer = (newtageSeit1900 - ((datumJahr - 1900) * 365) - oldschaltTage);

        sonderFall366 = LOW;
      }

      //Ansonsten muss mit dem aktuellen Wert der Schalttage (seit 1900) gerechnet werden
      else {
        tagNummer = (newtageSeit1900 - ((datumJahr - 1900) * 365) - newschaltTage);
      }

      //Aufruf der Funktion zur Berechnung des Monates
      datumMonat = welcherMonat(tagNummer, schaltJahr);

      datumTag = 0;

      //Berechnung der bereits vergangenen Tagen im Jahr
      for (i = 0; i < datumMonat; i++) {
        datumTag = datumTag + tageImMonat[i];
      }

      //Tag-Nummer minus bereits vergangener Tage im Jahr = aktueller Tag
      datumTag = tagNummer - datumTag;
    }

    //Ende: Datum ermitteln



    //Start: Sommer-/ Winterzeit einstellen

    //am letzten Sonntag im März (03) wird von UTC+1 auf UTC+2 umgestellt; 02:00 -> 03:00
    //am letzten Sonntag im Oktober (10) wird von UTC+2 auf UTC+1 umgestellt; 03:00 -> 02:00

    //Aufruf jeden Sonntag im März
    if (datumMonat == 3 && wochenTag == 7) {

      //Letzter Sonntag im März
      if ((tageImMonat[3] - datumTag) < 7) {

        //Umstellung auf Sommerzeit UTC+2
        utcx = 2;
      }
    }

    //Aufruf jeden Sonntag im Oktober
    if (datumMonat == 10 && wochenTag == 7) {

      //Letzter Sonntag im Oktober
      if ((tageImMonat[10] - datumTag) < 7) {

        //Umstellung auf Winterzeit UTC+1
        utcx = 1;
      }
    }

    //Sommer-/Winterzeit bei Neustart bestimmen
    if (utcx == 0) {

      //Neustart im Monat März
      if (datumMonat == 3) {

        //Neustart in der letzten Woche im März
        if ((tageImMonat[3] - datumTag) < 7) {

          //Beispiel Jahr 2020: März 31 Tage; Neustart 26. März 2020 (Donnerstag = Wochentag = 4); 5 Tage Rest; Letzter Sonntag 29. März 2020
          //Berechnung: 31 - 26 = 5; 5 + 4 = 9;
          //Ergebnis: Letzter Tag im März ist ein Dienstag. Es folgt noch ein weiterer Sonntag im Oktober => Winterzeit einstellen

          //Beispiel Jahr 2021: März 31 Tage; Neustart 30. März 2021 (Dienstag = Wochentag = 2); 1 Tage Rest; Letzter Sonntag 28. März 2021
          //Berechnung: 31 - 30 = 1; 1 + 2 = 3;
          //Ergebnis: Letzter Tag im März ist ein Mittwoch. Umstellung auf Sommerzeit bereits erfolgt => Sommerzeit einstellen

          //Es folgt innerhalb der letzten Woche im März noch ein weiterer Sonntag => Winterzeit einstellen
          if (((tageImMonat[3] - datumTag) + wochenTag) >= 7) {
            utcx = 1;
          }

          //Letzter Sonntag im März bereits vergangen => Sommerzeit einstellen
          else {
            utcx = 2;
          }
        }

        //Neustart in den ersten drei Wochen im März => Winterzeit einstellen
        else {
          utcx = 1;
        }
      }

      //Neustart im Monat Oktober
      if (datumMonat == 10) {

        //Neustart in der letzten Woche im Oktober
        if ((tageImMonat[10] - datumTag) < 7) {

          //Beispiel Jahr 2020: Oktober 31 Tage; Neustart 26. Oktober 2020 (Montag = Wochentag = 1); 5 Tage Rest; Letzter Sonntag 25. Oktober 2020
          //Berechnung: 31 - 26 = 5; 5 + 1 = 6;
          //Ergebnis: Letzter Tag im Oktober ist ein Samstag. Umstellung auf Winterzeit bereits erfolgt => Winterzeit einstellen

          //Beispiel Jahr 2021: Oktober 31 Tage; Neustart 26. Oktober 2021 (Dienstag = Wochentag = 2); 5 Tage Rest; Letzter Sonntag 31. Oktober 2021
          //Berechnung: 31 - 26 = 5; 5 + 2 = 7;
          //Ergebnis: Letzter Tag im Oktober ist ein Sonntag. Es folgt noch ein weiterer Sonntag im Oktober => Sommerzeit einstellen

          //Es folgt innerhalb der letzten Woche im Oktober noch ein weiterer Sonntag => Sommerzeit einstellen
          if (((tageImMonat[10] - datumTag) + wochenTag) >= 7) {
            utcx = 2;
          }

          //Letzter Sonntag im Oktober bereits vergangen => Winterzeit einstellen
          else {
            utcx = 1;
          }
        }

        //Neustart in den ersten drei Wochen im Oktober => Sommerzeit einstellen
        else {
          utcx = 2;
        }
      }

      //Falls Neustart der Uhr innerhalb der Sommerzeit (Ausnahme März/Oktober)
      if (datumMonat > 3 && datumMonat < 10) {
        utcx = 2;
      }

      //Falls Neustart der Uhr innerhalb der Winterzeit (Ausnahme März/Oktober)
      if (datumMonat < 3 || datumMonat > 10) {
        utcx = 1;
      }
    }

    //Ende: Sommer-/ Winterzeit einstellen



    //Start: Aktuelle Uhrzeit hh:mm:ss aus dem NTP-Paket ermitteln

    //Beispiel: Berechnung der aktuellen Stunde
    //Sekunden seit dem 1. Januar 1900 (3812811794) / Sekunden pro Tag (86400) = 44129 volle Tage seit dem 1. Januar 1900
    //Tage seit dem 1. Januar (44129) * Sekunden pro Tag (86400) = 3812745600 Sekunden der vollen Tage seit dem 1. Januar 1900
    //Sekunden seit dem 1. Januar 1900 (3812811794) - Sekunden der vollen Tage (3812745600) = 66194 Sekunden am aktuellen Tag vergangen
    //Sekunden des aktuellen Tages (66194) / Sekunden pro Stunde (3600) = 18 Stunden am aktuellen Tag vergangen => Aktuelle Uhrzeit 18:mm:ss

    //Berechnung der aktuellen Stunde
    utcaktstunde = ((newsecsSince1900 % secondperday) / secondperhour);

    //Berechnung der aktuellen Minute
    utcaktminute = (newsecsSince1900 % secondperhour) / secondperminute;

    //Berechnung der aktuellen Sekunde
    utcaktsekunde = (newsecsSince1900 % secondperminute);

    //Ende: Aktuelle Uhrzeit hh:mm:ss aus dem NTP-Paket ermitteln
  }

  //Ende: Datum und Uhrzeit ermitteln



  //Start: Uhrzeit über den millis()-Timer berechnen

  //Alle 1000 ms die Sekunden hochzählen
  if (millis() - lastmillisSecond > millisecondpersecond) {

    //Zeitdifferenz
    lastmillisdifferenz = lastmillisdifferenz + ((millis() - lastmillisSecond) - millisecondpersecond);

    if (lastmillisdifferenz > millisecondpersecond) {
      lastmillisdifferenz = 0;
      utcaktsekunde++;
    }

    //Systemzeit speichern für den nächsten Vergleich
    lastmillisSecond = millis();
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

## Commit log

2022-11-22 #1 korrigert und angepasst
    [WordUhr_DE_Esp8266.ino]
2022-11-25 #3 1. Bugfix - sporadische Zerstörung des Microcontrolers meist während des LED test am anfang... LED Helligikeit während LED test auf ein minimum verringert. für geringere stromaufnahme.. muss getes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
    [WordUhr_DE_Esp8266.ino]
2022-11-28 rahmen digital angefertigt/überarbeitet geprüft...
    [LayoutLED60ProMeter.skp, LayoutLED60ProMeter~.skp]
2022-12-27 name falsch
    [WordUhrSorb.xlsm]
